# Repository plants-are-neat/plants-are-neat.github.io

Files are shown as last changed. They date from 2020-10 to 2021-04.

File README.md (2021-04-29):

# Team 27 README
## Introduction
Hello, welcome to plants are neat! Throughout this project, we developed a mesh sensor network system capable of self-healing and communicating data from node to node. The data is routed through the network of nodes to find an access point to push data to the online database. The online database is a relational database organized through the thingspeak API to track independent channel ids, field ids, field values, and time data. We can pull the most recent data point to create google gauges with the most recent data point with this data. Notifications are handled through server-side react scripts and test the database to ensure data coming in is within given thresholds and that each node that should be in the network is successfully communicating data. Broken nodes are identified by a lack of data received by a gateway node over a 30 min period. This enables users to fix problems in the field without getting constant notifications. Broken nodes check for fixes every 30 minutes.

## Getting Started
1. Populate the PCB using the schematic and BOM.
2. Solder wires to the battery breakout and have them ready to connect to the battery, but do not connect the battery yet.
3. Install the vent plugs into the enclosure.
4. Drill holes into the enclosure for the external antenna, soil temperature sensor, soil moisture sensor, and the solar panel DC jack.
5. Thread the soil moisture sensor and the soil temperature sensor through the holes and solder them into place using the schematic.
6. Screw the PCB into the enclosure.
7. Using weatherproof epoxy, fix the antenna, soil sensors, and solar panel DC jack into place and let cure overnight.
8. Upload any relevant code to the Featherboard using the Software_README.md file.
9. Insert the Featherboard into the PCB.
10. Connect the solar panel DC jack to the PCB DC jack.
11. Connect the battery to the battery breakout on the PCB.
12. Close the enclosure and place it in the proper location.
13. Open .ino using Arduino IDE
14. Connect Feather M0 to computer using usb-microusb
15. Hit ‘Upload’ on upper left-hand corner
16. Wait for upload to finish
17. Install NODEJS https://nodejs.org/en/download/
18. Make sure MotherNode is connected to computer, CANNOT be used by another program, connection will be blocked
19. Open command prompt
20. Go to directory where file is
21. Run command "Node SerialTest.js”
## Current State
The current state of the project features a mother node requesting data from all the outer nodes, and the outer nodes collect data (soil moisture, soil temperature, ambient temperature, humidity, and sunlight intensity) and sending the data to the network. As stated in the introduction, the project also includes a thingspeak API, graphical representation of the collected data, and broken node email notifications.
## Failure Modes and Gotchas
| Gotcha  | Reason | Solution |
| --- | --- | --- |
| Boost converter auto bypass nonfunctional | The MOSFETs’ gate voltages are not defined at startup | Use pullup resistors on the MOSFET gates to Vcc |
| COM port disconnects | COM ports can disconnect after successfully uploading code to the Featherboards | Use the Arduino IDE to pick the new COM port corresponding to the correct Featherboard |
| Delayed email notifications | gmail firewalls | alternative notification system |
| Self healing requires correct installation | If each node is not installed within range of at least two other nodes, the network may not be able to self heal | Make sure that each sensor node is installed within range of at least two other sensor nodes |
| NODEjs crashes upon selecting a port | Serial ports can’t be read using different programs simultaneously | Close all other applications reading or writing to the port, most likely culprit is the Arduino IDE | 
## Possible Future Improvements
- Expanding the node network beyond our test 4, integrating automatic node IDs and being able to toggle between all of these data displays
- Change visualisation page to display multiple nodes at once. 
- Expanded sensor readings
- Use wifi-enabled board so it can run continuously
- Fix boost converter auto-bypass issue
- Use a Raspberry Pi as a continuously running server that can read serial data via USB input

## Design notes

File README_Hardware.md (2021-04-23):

# Team 27 Hardware README
## Introduction
The smart agriculture sensor network is comprised of sensor nodes and one gateway node. The gateway node is simply a LoRa-equipped microcontroller, namely the Adafruit FeatherM0 LoRa microcontroller board. The sensor nodes also include a LoRa microcontroller, but it is mounted on a PCB that includes all of the power electronics and all of the sensors for the sensor node. All schematics and layouts can be found in the directory "Schematics and Layouts".

## System Design
The gateway node electronics consist solely of the Adafruit FeatherM0 LoRa microcontroller board, which is connected to a laptop or desktop computer via a micro-USB cable. The sensor nodes, however, are more complex. 

The sensor nodes are capable of measuring ambient temperature, humidity, ambient light, soil moisture, and soil temperature. There are breakouts on the PCB so the user can add more sensors that may be more specific to the farming task. The sensor nodes also features solar energy harvesting with a solar panel and a solar battery charging and power path management system. Thus, the requirements met by the hardware of the project are: 
1. The sensor nodes must be powered for one year continuously.
2. For 100 sensor readings in identical conditions, the sensor data should not deviate by more than +- 5% of the mean.

Requirement number 2 is met by the onboard sensors, which use the I2C protocol if they are digital sensors and act as voltage dividers if they are analog sensors. The LoRa Featherboard is natively I2C compatible, so it can poll the digital sensors without any additional components which are not recommended by the sensor manufacturer. The Featherboard also has an on-board analog-to-digital converter (ADC), so there is no need for a separate external chip to allow the processor to communicate with the digital sensors. Requirement number 1 is met by the power path management and solar battery charging system. These two subsystems are discussed in detail in the PCB Design section.

The sensor node consists of a populated PCB, an Adafruit FeatherM0 LoRa microcontroller board, an external antenna, a battery pack, an enclosure and other mechanical components, and a solar panel. A bill of materials for one sensor node is presented below. Recall that the gateway node consists solely of one Adafruit Featherboard, and is not listed here. Also included in this BOM is the soil moisture sensor, which is not available at Digikey. All other components for the PCB were purchased at Digikey and are available in the PCB Design section.

### Sensor Node Equipment BOM
| Item Number  | Item | Vendor | Link | Quantity |
| --- | --- | --- | --- | --- |
| 1 | FeatherM0 LoRa microcontroller | Adafruit | [Link](https://www.adafruit.com/product/3178) | 1 |
| 2 | Large 6.5V 3W solar panel | Adafruit | [Link](https://www.adafruit.com/product/500) | 1 |
| 3 | ICR18650-30Q Li-Ion Battery Cells | 18650 Battery Store | [Link](https://www.18650batterystore.com/products/samsung-30q) | 4 |
| 4 | Custom PCB | JLCPCB | N/A | 1 |
| 5 | VH400-2M soil moisture sensor | Vegetronix | [Link](https://www.vegetronix.com/Products/VH400/#order) | 1 |
| 6 | Nema 4X enclosure | Solutions Direct | [Link](https://www.solutionsdirectonline.com/hammond-4x7x7-polycarbonate-electrical-enclosure-with-clear-cover-1554wa2gycl) | 1 |
| 7 | Pressure equalization vents | Solutions Direct | [Link](https://www.solutionsdirectonline.com/enclosure-vent-plug-m12-x-15-2-pack--284060-00-p6062.aspx) | 1 |
| 8 | LoRa 900MHz antenna | Adafruit | [Link](https://www.adafruit.com/product/3340) | 1 |

The Featherboard is inserted into the assembled PCB as directed by the silkscreen. The battery is connected to the P1 breakout on the PCB with the battery positive going to the square hole. The solar panel male DC jack is inserted into the female DC jack on the PCB. When populated and programmed, the hardware should be powered, be able to run, collect data, and send and receive packets via LoRa.

The system requires at least 4.5V at the DC jack input to function without battery power, so for testing purposes a 5V wall adapter will work. The maximum input voltage at the DC jack is 10V. Since the solar panel can only output an open circuit voltage maximum of 6.5V, this shouldn't be an issue, but the PCB has a zener diode to clamp the input voltage in case of emergencies. The PCB also has a boost converter for low light conditions, which is discussed in the PCB design section.

The Featherboard uses an external 900MHz antenna for long distance communication with other sensor nodes. It is installed on the outside of the enclosure so that line-of-sight is not obstructed.

Pictures of the assembled system are shown below:

### System Images
Hardware angle 2
Hardware angle 4

## PCB Design
The PCB consists of three main sections:
1. Input power electronics and solar charging and power path management.
2. Featherboard harnessing and breakouts.
3. Digital and analog sensors.

An image of the rendered PCB layout with the above sections marked is shown below:
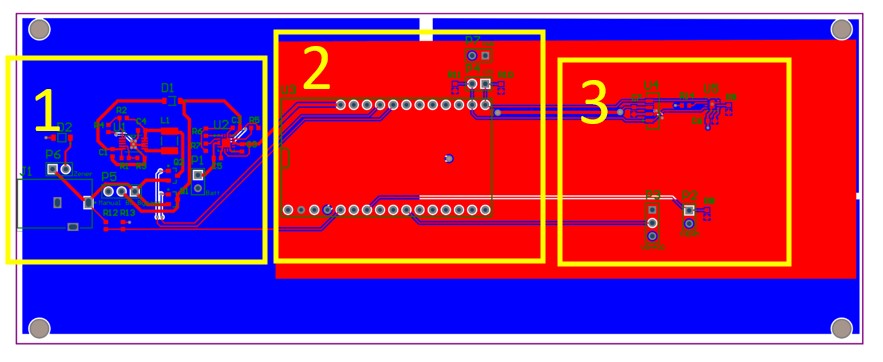
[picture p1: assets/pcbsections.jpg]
PCB Sections


### PCB Section 1: Power Electronics
The largest and most important subsection of section 1 of the PCB is the solar charging and the power path management, which is accomplished using the BQ24074 (item #2 in the PCB BOM). The BQ24074 is a standalone 1.5A linear battery charger with power path management. The design of this IC on the PCB was implemented using the application notes section of the datasheet provided by Texas Instruments and accessed from Digikey. Using the application notes, the Enable pins E1 and E2 were tied high and low respectively, causing the IC to be USB compatible with a maximum input current of 500mA. A temperature sensor for the battery pack was not implemented, so in it's place a 10k resistor was selected as R7 to permanently cause the IC to be active. R5 and R6 were selected to both be 2.2k, which makes the input current limit and the fast charging current to be the same value, and is set to 400mA. The input and output capacitors as well as the bypass capacitors were selected based on the application notes' recommended values. The PCB layout of this subsection was informed by the layout recommendations in the application notes, with special considerations for hand-soldering of SMD parts and the placement of the PCB and battery within the enclosure.

The other main subsection of section 1 is the low-light boost converter, which boosts the solar voltage to a level that will operate the Featherboard and sensors in low-light conditions so that the battery does not have to discharge as much. This is accomplished using the MCP16414 (item #1 in the PCB BOM). The MCP16414 is a low quiescent current low input voltage minimum programmable boost converter. The design of this IC on the PCB was implemented using the application notes section of the datasheet provided by Microchip and accessed from Digikey. R1 and R3 were selected to be 1.5Meg and 360k respectively to give an output voltage of 5V, as specified in the application notes. The switching inductor as well as the input and output capacitor values were also taken from the application notes' recommended values for 5V output operation. The PCB layout of this subsection was informed by the layout recommendations in the application notes, with special considerations for hand-soldering of SMD parts. 

The MCP16414 maximum input voltage is 5.25V, and since the solar panel output can reach 6.5V, an automatic bypass system was implemented using P-channel MOSFETs (Q1 and Q2 in the PCB BOM), which are controlled by the Featherboard. This subsection is currently experiencing a bug where the MOSFET gates are floating on startup, and thus the boost converter is not properly bypassed, which causes the input voltage to short to ground through the boost converter. A better solution for future beta versions of the project would be to implement the automatic bypass with analog electronics, so that the propagation delay of the control signals to the P-channel MOSFETs is much less. Additionally, including pull-up resistors and diodes (to the solar panel input and the battery positive) on the MOSFET gates will establish a gate voltage immediately. This issue was known prior to the end of the semester, but was not implemented in the alpha version of the project due to issues with working remotely and time constraints. The entire system needed to be passed around for other tasks, and in order to have a completed project by the end of the semester this issue was not addressed, although there are proposed solutions presented here.

### PCB Section 2: Harnessing and Breakouts
This section is where the Featherboard is inserted into the PCB. The section also includes 3.3V and ground breakouts to power other sensors, as well as I2C clock and data line breakouts for exteral digital I2C compatible sensors.

### PCB Section 3: Sensors
This section consists of the digital and analog sensors that are polled by the Featherboard. The sensors used are:
* SHT31-D (item #4) to measure ambient temperature and humidity.
* VEML7700 (item #3) to measure ambient light.
* 10k NTC thermistor with K constant 3435K (item #19) to measure soil temperature.
* VH400-2M (item #5 in the system design BOM) to measure soil moisture.

The digital sensors were implemented on the PCB and their layout was done using the application notes in their datasheets provided by Sensirion (SHT31-D) and Vishay (VEML7700) and accessed from Digikey. The VH400 was connected according to the tutorials provided by Vegetronix, and the thermistor was connected in a voltage divider configuration according to a tutorial made by Adafruit. Both the digital and analog sensors are powered from the Featherboard's on-board 3.3V regulator. The analog sensors are grounded via a ground plane that spans the entire PCB, including the power electronics. The digital sensors were grounded separately from the analog sensors, and were grounded directly to the Featherboard ground in order to eliminate any capacitive coupling from the power electronics via the large ground plane.

### PCB BOM
| Item Number | Designator  | Value | Footprint | Quantity | Digikey Part # |
| --- | --- | --- | --- | --- | --- |
| 1 | U1 | MCP16414-I/UN | MSOP-10 | 1 | 150-MCP16414-I/UN-ND |
| 2 | U2 | BQ24074RGTR | 16-QFN | 1 | 296-38873-1-ND |
| 3 | U4 | VEML7700-TR | 4-SMD, J-LEAD | 1 | VEML7700CT-ND |
| 4 | U5 | SHT31-D | 8-VFDFN | 1 | 1649-1011-2-ND |
| 5 | Q1,Q2 | STR2P3LLH6 | SOT-23 | 2 | 497-15520-1-ND |
| 6 | J1 | PJ-102B | DC Jack | 1 | CP-102B-ND |
| 7 | D1 | RB161MM-20TR | SOD-123F | 1 | RB161MM-20CT-ND |
| 8 | D2 | MMSZ5233BT1G | SOD-523 | 1 | MM5Z5V1ST1GOSCT-ND |
| 9 | L1 | 4.7uH | 1812 (4532) | 1 | 490-2517-1-ND |
| 10 | R2,R4,R10,R11 | 4.7kR | 0603 (1608) | 4 | CRCW06034K70JNEBCCT-ND |
| 11 | R5,R6 | 2.2kR |  0603 (1608) | 2 | 541-4058-1-ND |
| 12 | R7,R8,R9,R12,R13 | 10kR | 0603 (1608) | 5 | 13-RE0603FRE0710KLCT-ND |
| 13 | R1 | 1.5MR | 0603 (1608) | 1 | 311-1.5MGRCT-ND |
| 14 | R3 | 360kR | 0603 (1608) | 1 | 311-360KGRCT-ND |
| 15 | C1,C4 | 10uF | 0603 (1608) | 2 | 478-10766-1-ND |
| 16 | C2 | 1uF | 0603 (1608) | 1 | 587-1248-1-ND |
| 17 | C3,C5 | 4.7uF | 0603 (1608) | 2 | 1276-1902-1-ND |
| 18 | C6,C7 | 100nF | 0603 (1608) | 2 | 1276-1931-1-ND |
| 19 | P2 | 10k NTC 3435K | 2-LEAD | 1 | BC2647-ND |

## Installation and Instructions for Engineers
Instructions on how to assemble and install a sensor node are listed below:
1. Populate the PCB using the schematic and BOM.
2. Solder wires to the battery breakout and have them ready to connect to the battery, but do not connect the battery yet.
3. Install the vent plugs into the enclosure.
4. Drill holes into the enclosure for the external antenna, soil temperature sensor, soil moisture sensor, and the solar panel DC jack.
5. Thread the soil moisture sensor and the soil temperature sensor through the holes and solder them into place using the schematic. 
6. Screw the PCB into the enclosure.
7. Using weatherproof epoxy, fix the antenna, soil sensors, and solar panel DC jack into place and let cure overnight.
8. Upload any relevant code to the Featherboard using the Software_README.md file.
9. Insert the Featherboard into the PCB. 
10. Connect the solar panel DC jack to the PCB DC jack. 
11. Connect the battery to the battery breakout on the PCB. 
12. Close the enclosure and place in the proper location.

Note: for optimal self-healing performance, place each sensor node within range of at least two other sensor nodes.

To install the gateway node, plug it into a laptop or desktop computer using a micro-USB cable, connect the external antenna, and follow the instructions in the Software_README.md file.

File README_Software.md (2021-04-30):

# Team 27 Software README
## Introduction
The smart agriculture sensor network is comprised of sensor nodes and one gateway node. The project requires a node.js server to communicate with the ThingSpeak IoT channels. While the project was developed in a Windows operating system environment, most of the files can be run in different operating system except for the batch files. Correct installation of node.js is also required to allow the project to work properly. The outer microprocessors (nodes) are flashed with a program that allows them to collect sensor data when not sleeping to conserve energy. The node.js server receives information from the mother microprocessor via serial communication to be sent to a remote website.

## Files
CODE ON ARDUINO IDE:
Adafruit Library installed
 1. Sensor_Node_X.ino:
 
This program serves as the outer node code for nodes with sensors out in the field. It starts off by initializing the radio unit on the onboard feather and setting pins as outputs and inputs for the sensors on board. Each sensor runs through its own initialization. The radio unit has fail safes that does not let the code run if it does not initialize properly. The code then executes. It takes the reading from its sensors, puts the readings in a string, and then sends the string through the radio. Collected information will depend on the user's decisions on what to implement. In this project, the node will collect humidity, soil and ambient temperature, soil moisture, and sunlight intensity. The radio library allows for rerouting in the case of a broken node and self healing as well. The message gets routed all the way to the mother node. After sending the message the board activates its sleep protocol and 'sleeps' turning off most systems to conserve power. It wakes up after a set amount of time and repeats. The sleep function allows the use of the microprocessors specific power modes thus the need of other libraries might be necessary.

    -C++/C
    -Dependencies
      -RadioHead.h             // For the onboard radio
      -SPI.H                   // For on board communication with the sensors 
      -Adafruit_VEML7700.h     // Ambient light sensor
      -Adafruit_SHT31.h        // Humidity sensor
      -Adafruit_SleepyDog.h    // Sleep protocol for the board

 2. client_node.ino

This program serves as the mother node of the network. Starts off by initializing the radio. Periodically polls the other nodes with sensors and polls them to give it information. Upon receiving a message, it prints it out to the COM port for the computer to read. Repolls and repeats.
    -C++/C
    -Dependencies
      -RadioHead.h             // For the onboard radio
      -SPI.H                   // For on board communication with the sensors 
--TO RUN--
1. Open .ino using Arduino IDE
2. Connect Feather M0 to computer using usb-microusb
3. Hit Upload on upper left-hand corner
4. Wait for upload to finish

CODE ON DEKSTOP
NODEJS installed
  1. SerialTest.js

SerialJS does a few things for the mesh. Firstly, it uses an external library to prompt the user for which active port to use. IMPORTANT: The code cannot execute if another program, such as the Arduino IDE is using the COM port, meaning if the Serial Monitor is open and listening in on the COM port it will terminate with an error. Terminating with an error should be avoided. It then reads from the port and saves it within the code to use the second library to send it over to the ThingSpeak IoT channel. The message from the arduino is then chopped up between the partitions, in this case commas, and sent to their specific fields. It then repeats this and sends whenever there is a new message. Messages that are way below and above certain thresholds are deleted and ignored.
     -NODEJS
     -Dependencies
        -ThingSpeakClient    // For updating the ThingSpeak channel
        -serialport          // For reading the serial COM port
        -prompt-sync         // Used for prompting the user
--TO RUN--
1. Install NODEJS https://nodejs.org/en/download/
2. Make sure MotherNode is connected to computer, CANNOT be used by another program, connection will be blocked
3. Open command prompt
4. Go to directory where file is
5. Run command "Node [FILENAME]" where [FILENAME] is the name of the file with the extension

CODE ON WINDOWS
1. PANinstall.bat

_TITLE Dependencies Installation
ECHO Installing dependencies, please wait!                              //Echo just prints out a statement
npm install thingspeakclient                                            //installs the thingspeak client library
npm install serialport                                                  //installs the serial reader
npm install prompt-sync                                                 //installs the prompt to ask the user
ECHO All dependencies downloaded, thank you for your patience!          //Prints out the final message
PAUSE                                                                   //Waits for a user input to move_

This batch file is made for the simplicity of the user. Since the developing team consisted of only window users, the installation and batch file was developed only for a windows environment. As a result, future improvement include the implementation of the batch file to work in different operating systems like iOS, Linux, Unix, etc. This batch file installs all NODEjs libraries. It executes and downloads the libraries and waits for the user to close the command prompt.

2. runMESH.bat

_node SerialTest.js                                                     //THis is how a js script is ran
PAUSE                                                                   //Leaves the prompt open, do not stop the prompt_

This batch file is made for the simplicity of the user. On the team, there are only windows users so we could not develop this for other operating systems. This batch file executes the SerialTest.js. It runs and the promp should be left open for the code to keep executing.

  -Dependencies
    -SerialTest.js
--TO RUN--
1. Open any command prompt
2. Go to where the .bat files are (they should be grouped together, with the NODEJS code)
3. Double click PANinstall.bat first, runMESH may not run if done out-of-order
4. Double click runMESH.bat

## Libraries
The main two libraries used in the nodes are RH_RF95 and RHMesh. Both libraries are part of a larger library named RadioHead that allows the use of long range (LoRa) radio communication installed in the Arduino. 

RH_RF95 allows the use of two radio wave (868 and 915) lengths. To comply with US regulations, we chose 915 as the default wave length of the network. This can be changed to 868 at the top of each file depending on the user’s country’s regulations. The library is the foundation of the other libraries since the library grants the ability to send and receive packages of information via an object-oriented format. The library consists of drivers and managers to modulate the communication requirements of different microprocessors. While this library allows the communication between nodes, further libraries are needed to achieve the mesh network behavior of route discovery, creation and maintenance of a routing table, and self-healing capabilities. As a result, the next library is needed. Further documentation can be found here: https://github.com/kenbiba/RH-RF95 

RHMesh allows the use of a mesh network behavior into the microprocessors instead of naive communication protocols. It includes automatic route discovery when initializing the drivers and managers as well as multi-hop routing capabilities thus allowing self-healing if a node is corrupted/broken. This is achieved via the use of routing tables first initialized when initializing the manager and sending the first message to the desired address/location. Even if the message fails to send to the desired node/location, the intermediate nodes are registered into the routing table for an up to date information on the most efficient route to each node. A future improvement to the library can be to decrease the situations that create races. The library is an extension of a different library called RHRouter which is the foundation of the RHMesh library. Further documentation can be found here: https://www.airspayce.com/mikem/arduino/RadioHead/classRHMesh.html 

The two main libraries used in the desktop are the serialport and the ThingSpeakClient libraries. Both are independent of each other and are stand-alones.

ThingSpeakClient enables communication with ThingSpeak's servers. There are built in functions for validating requests to read or write and alraedy has all the information necessary to initiate communication between the servers. The library also has built-in functions for enabling the coder to write to specific graphs within the channel. There are a few limitations with the library. Depending on what specific service the user has with ThingSpeak, there is a possibility of messages getting backlogged. For the purposes of this however, unless nodes exceed a normal amount, should not happen.

Serialport enables communication with usb enabled devices. The library uses a parser as well to be able to read what is inputed into it. It takes whatever it receives and is saved on memory. Using this instead of other means that it is incredibly reliable due to built-in error finding on computers when compared to wireless means. If the port is being used by another program it will exit with a fatal error.

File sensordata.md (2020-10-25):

---
title: Sensor Data
layout: default
---
### Sensor Data
The following is an example how data will be presented: <br>
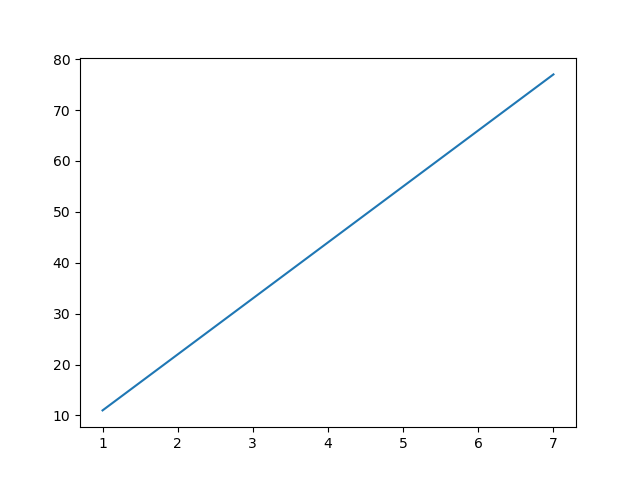
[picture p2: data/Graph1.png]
hi


### Current nodes offline include:
None at the moment

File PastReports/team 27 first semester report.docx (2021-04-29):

ENG EC 463 – Team 27

Smart Agriculture Sensor Network

First Semester Report

Benjamin Livney, Maxine Loebs, Sergio Pareja, Emanuel Perez and Noah Spahn

Executive Summary (M.L.)—Farming is paramount to society. Throughout history, as global populations have increased, farming methods have had to improve to keep up with growing demand. Today, the situation is no different – with more and more mouths to feed, farmers are looking to modernize their practice and adopt technologies that can help them boost crop yields, reduce waste, save money, and stay afloat among industrial-scale agricultural corporations. To address this need, we will be developing a fully-functional agricultural sensor network, which reports data about specific locations on the farm back to the user in the comfort of their farmhouse. We have come up with a detailed plan to realize our design. The backbone of our final product is our sensor nodes. These will contain our selected sensors, a microcontroller equipped with a radio transceiver, and the required hardware to supply power to all of the electronics inside. All of the components will be put into a weatherproof enclosure. All of these nodes will be connected together in a scalable mesh network. The data from all of the nodes will be pooled into a single gateway node, which will then send compiled data to our web console. Our web console will present this live data in a neat, readable format. There are other agricultural sensor networks on the market, but our product will include a number of innovative features that make it stand out, such as energy harvesting, and the use of a wide variety of sensors to paint a full picture of many conditions out in the field.

—————————— ——————————

# 1 Introduction (M.L.)

In recent years, farmers have been embracing technology to supplement and/or replace more traditional farming methods in order to increase crop yields, lower the cost of production, reduce waste, and – in the case of smaller, local farmers – remain profitable and competitive in a market that is dominated by large-scale agricultural corporations.

As such, we are being tasked with creating an agricultural sensor network to help accomplish all of these things. The network will allow the farmer to be aware of the conditions at any location on his farm at which an individual sensor node is placed, all without having to actually step foot out into the field, as the data will be available to view on a web console. This saves time and money. The farmer doesn’t have to drive around the farm himself to check on things, or pay people to do the same. Some farms – even those owned by small farmers – are massive in size, so checking up on areas of the farm could become quite time-consuming, even when done only once a day. Having insight into the current conditions around the farm additionally allows the farmer to save money by being able to better distribute resources. For example, the device will have a soil moisture sensor. By monitoring soil moisture, the farmer can in turn adjust how much he is watering different areas of his fields, preventing overwatering and in hand saving money. With knowledge of field conditions, the farmer can make adjustments to ensure ideal conditions for achieving the most successful crop, and thus achieve higher profits.

We have come up with a detailed plan for the implementation of our design. Our network will consist of sensor “nodes” which will collect and relay data back to a single gateway node. These sensor nodes will, as the name would suggest, contain all of our sensors. We are planning to gather data pertaining to air temperature, humidity, barometric pressure, ambient light, soil temperature, and soil moisture. The data readings give the farmer a full picture of their crop’s current environment. Since the information needs to get back to the farmer, each node is also equipped with a transceiver. We will set up a mesh network protocol that will allow information to bounce from node to node until it gets back to the gateway. If one node in the chain is not able to relay data, the mesh networking protocol will allow for a new route to be discovered. Of course, both the sensors and the microcontroller need to be powered. We will use both a battery pack and a solar panel to provide power. The solar panel can also recharge the batteries. The electronics will be housed in a weatherproof container, which will protect our electronics from rainfall, windblown dust and dirt, and the formation of ice in colder months. The gateway node, which will be located in the farmhouse, is where all the data will be pooled from all of the sensor nodes out in the field. In addition to a transceiver, this node will also have a co-processor that will allow data transmission over WiFi to our web console. Our web console, upon receiving live data, will display the data in graphs that will allow the user to see changes in conditions over time. This is a powerful tool, since seeing trends of data, rather than just individual points in time, further allows the farmer to make predictions and adjustments in his plan to achieve the best crop.

There are other products on the market that seek to accomplish the same goal as our prototype: to provide farmers data about their farms via a network of sensors. We are including a number of features that make our product different. We will be using a number of different sensors, mentioned previously, that will provide the farmer with a multitude of data pertaining to both atmospheric and soil conditions. Many companies only produce nodes that report back one type of data reading, or require users to purchase several different models to get a wider variety of data. Additionally, with the use of energy harvesting, we are greatly able to extend the battery life of our nodes. In fact, our nodes will be able to last at least one year between charges. Many companies rely solely on battery power for their nodes, so they need to be recharged much more frequently, creating more work for the farmer.

# 2 Concept Development (M.L.)

To develop our concept for design, we identified key functions to be fulfilled by our prototype, and then came up with solutions to address each function.

Our sensors must operate as a network, and therefore communicate with each other, and not just with the gateway node. As such, we decided to use a mesh networking protocol. This has a number of benefits. Broken or unresponsive nodes can be identified, and since signals bounce from node to node in a mesh back to the gateway, a new route can be discovered to avoid the broken node until it is repaired, so that all other data from working nodes can still make its way back to the user. Since we are not sending data directly back to the gateway, but rather bouncing the signal back via other nodes, we also do not need a massive signal transmission range.

With the basis of our network established, we had to choose how our data would be transmitted. Eventually, we decided to use LoRa (Long Range) RF transmission-equipped microcontrollers. The microcontrollers, with the proper antennas, are able to transmit data across several kilometers while using very little power. We have set our node-to-node transmission range goal to be between 750 m and 5 km. We had considered some other methods of data transmission, such as equipping our nodes with SIM cards to connect to a cellular network, but we soon decided that this would become expensive, complicated, and use too much power.

Our nodes must be able to last at least one year between charges. This means that we had to carefully consider what devices we would use and how much power they would draw, and what we would use to provide power. At first, we considered just equipping the nodes with a massive battery pack, but we decided that this would become too bulky if they had to last an entire year, and that we were capable of something more innovative. It was suggested that we look into energy harvesting. We looked into both solar and thermoelectric energy harvesting. Ultimately, solar energy harvesting with a solar panel was the clear winner, as we were able to propose an implementation that would provide a much greater amount of power. So, our final powering solution consists of a combination of battery pack and a solar panel. The solar panel can recharge the batteries and supply power directly to the electronics inside the node as well.

The information that we are sending back to the user must be useful for farming. We carefully considered the sensors that we would be using in our prototype – air temperature, humidity, barometric pressure, ambient light, soil temperature, and soil moisture – making sure that the information they provided could be used to gain insight into how to achieve the best crop. We also considered including a sensor to measure soil pH, but these kinds of sensors, however, require relatively involved and individual calibration.

Lastly, we needed to make sure that our sensor nodes are weather-resistant. Water and dust should not be able to get inside of our node and damage our electronics. We researched different weathe-rproofing standards, and determined to aim for at least IP43 compliance, which would protect our electronics from spraying water.

We have tabulated a formal list of engineering requirements, that can be quantifiably measured, in Appendix 1.

# 3 System Description (B.L.)

As a solution, a mesh sensor network utilizing the LoRa communication protocol will be developed. The network will consist of many sensor nodes outfitted with relevant sensors, energy harvesting equipment and electronics, and a LoRa RF-equipped microcontroller. The network will also have a gateway node to collect data from the sensor nodes and push it to a web console to be viewed by the user.

Each sensor node will be outfitted with a solar energy harvesting system incorporating a small photovoltaic (PV) module and power electronics to maintain power for at least one year. Nodes will be equipped with a 3W 6.5V PV module capable of providing a maximum of 460mA in high light conditions. In order to not drive the module too hard, a maximum battery charging current of 400mA is set by the battery charge IC, the BQ24074. For low light conditions, a low-power boost converter, the MCP16414, will boost voltages above 1V up to 5V to operate the BQ24074 correctly and to power the microcontroller and sensors. The boost converter will have both a manual and an automatic bypass to ensure use only in low-light conditions to maximize efficiency, and to ensure the maximum input voltage to the boost converter of 5.25V is not exceeded. The battery pack will be between 12000mAh and 18000mAh, which will ensure sufficient power for three weeks with no sun, assuming an average current draw of 25mA from the microcontroller and sensors. This large backup battery will help meet the power budget requirements in conjunction with the solar energy harvesting system.

The sensor nodes will feature both digital and analog sensors capturing data to represent a variety of factors that affect growing conditions. The sensors will consist of: the BME280 to measure temperature, humidity, and barometric pressure, the VEML7700 to measure ambient light intensity, the VGH400 to measure soil moisture, and an NTC thermistor to measure soil temperature. Monitoring these quantities are basic necessities in order to create optimal growing conditions. For more specific applications, additional digital and analog sensors can easily be added to reflect the needs of a specific location. Additional sensors could include UV index sensors for UV-specific crops and motion sensors for wildlife tracking.

The LoRa communication protocol allows for wireless communication and mesh networking between LoRa-enabled devices using a tunable 900MHz carrier signal without the need for cell service, Wi-Fi, or Bluetooth capabilities. This protocol will be used to create the mesh sensor network by establishing a gateway node that sends poll requests and waits for responses. As shown in Figure 1, each sensor node will listen for incoming LoRa messages, either from the gateway node or from other sensor nodes. If the incoming message is not a poll request, meaning the message contains sensor readings, the sensor node will use the established mesh protocol using LoRa to repeat that message, sending it closer to the gateway node for analysis. If the incoming message is a poll request, the sensor node checks if it is polling itself, in which case it takes sensor readings and sends them to the mesh network. Otherwise, it repeats the poll request so that other nodes out of range of the gateway can receive it.

The gateway node will, at regular intervals, send poll requests to the mesh network for data from specific sensor nodes. As described above, the sensor nodes will echo the poll request until it reaches its destination, at which point the data will be sent and echoed back. If the gateway node receives a response before a timeout, it will push it to the web console for processing using an ESP8266 Wi-Fi enabled module. If no response is received before the timeout, the gateway node will push a notification to check the status of the requested node. Since the network should be installed such that every node is in range of multiple other nodes, there will be many paths from the gateway to any requested node. Thus, if a timeout occurs, the gateway will know that the requested node is at fault and not some other sensor node.

Once sensor readings from sensor nodes have reached the gateway node, the data will be processed by ThingSpeak IoT, a free IoT data visualization tool running off of MATLAB. This tool can create live-updating graphs using MATLAB plotting functions that run as embedded HTML divs. The gateway node, running inside the farmhouse, will have access to Wi-Fi, and thus will send sensor readings to ThingSpeak IoT, which will store, plot, and update the data live in an HTML webpage for the user to see. Data will not be pushed and stored in a JSON object, which can be read by ThingSpeak IoT.

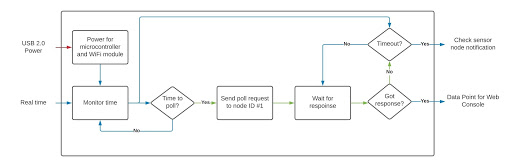
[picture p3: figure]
Word template Figure 1

Fig. 2. A functional analysis of the gateway node describing poll requests, responses, and interaction with the web console.

# 4 First Semester Progress

## 4.1 Current Network Protocol (E.P.)

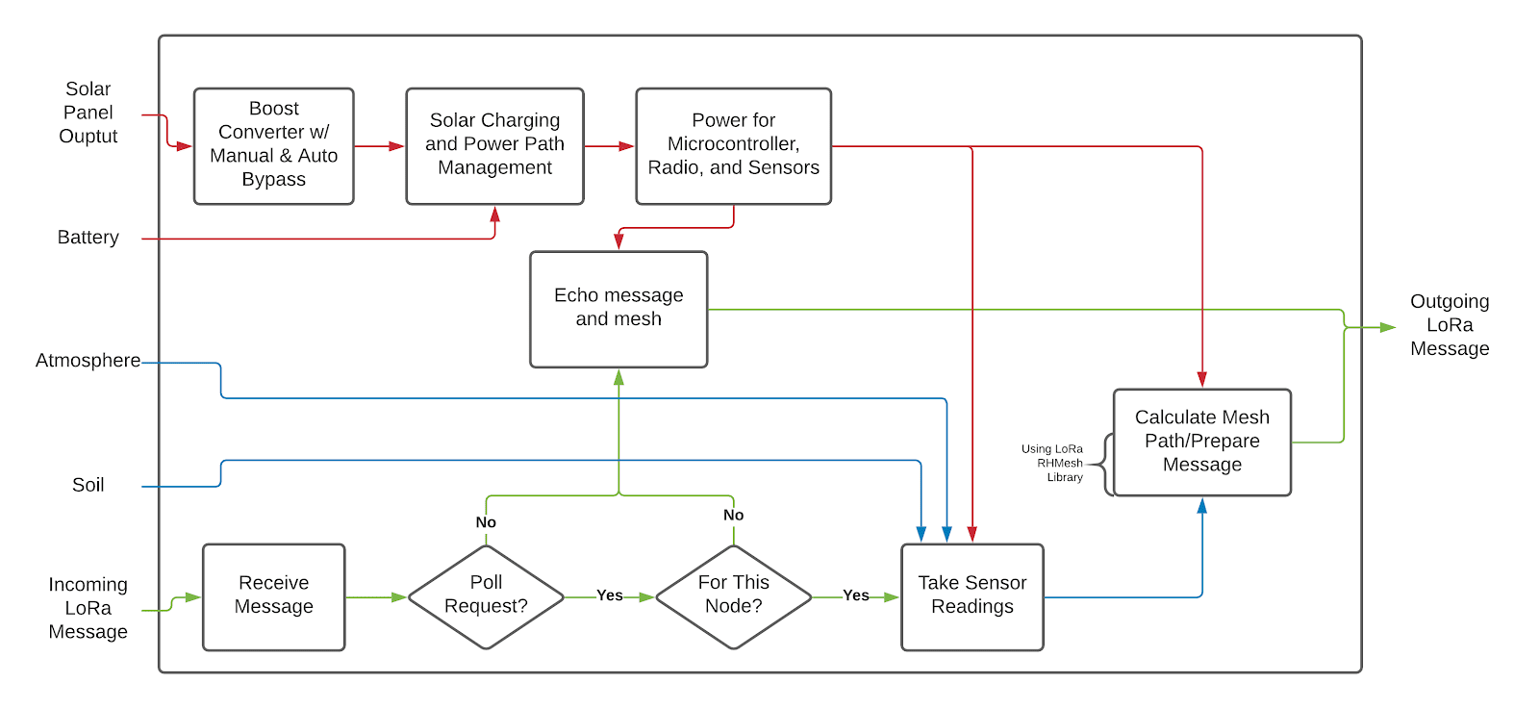
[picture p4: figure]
Word template Figure 1

Fig. 1. A functional analysis of a sensor node describing power flow, sensor operation, and LoRa mesh networking.

During the first prototype testing, we used a different network protocol than the mesh network to test the communication between our nodes. Similar to the mesh network, the network consists of a mother node (gateway node) and outer nodes (sensor nodes). The mother node sends poll requests for a specific node to the network. With the use of the LoRa microcontroller, the poll is sent via radio waves to nearby listening nodes. The receiving nodes will send an acknowledgement depending on whether or not it’s the node the mother node is looking for. If it is, the node will send the current sensor data back. If it isn't, it will send a simple acknowledgement and send the poll to other nearby nodes.

## 4.2 Power Management (E.P.)

To meet the client’s battery life expectancy of one year, the device has the ability to sleep/wake for an X amount of time. During the device’s sleep cycle, all electronics and internal functions are stopped. Once X amount of time passes, the device is woken up via a watchdog timer. If the desired amount of sleep is greater than the watchdog timer’s limit, then the device wakes up momentarily to sleep again till it reaches the desired amount. The current sleeping protocol can save up 40% of energy consumption than just the device being idle.

## 4.3 Power Electronics (B.L.)

For the first prototype test, we demonstrated the power path management abilities of the proposed system. We were able to charge a Li-Ion battery through the power path management IC, deliver power to a load from an external power supply through the IC, and power the same load from the battery through the same IC. From previous testing, it was shown that the battery could be charged from the solar panel with up to 160mA on a partly-cloudy New England winter day, and with up to 50mA while obstructing the solar panel, simulating shadows. This IC was then integrated into a PCB, also including low-light power adjustment with a boost converter, as well as the microcontroller and sensors. Schematics for the power electronics and sensor electronics are shown in Appendix 3.

## 4.4 Power Electronics (B.L.)

Using the I2C communication protocol, we were able to demonstrate data collection from multiple digital and analog sensors at once, and the formatting of data points into a string to be sent by the LoRa module. This was accomplished with the use of sensor breakout modules, inexpensive PCB sensor products meant for modular testing and projects that do not feature best practice layout techniques: ground between the data lines to reduce crosstalk and star grounding with separate ground planes for analog and digital sensors. The PCB we designed does feature those best practices, which will serve to improve reliability and precision in data collection. Schematics for all the electronics, as well as a preliminary PCB layout, are shown in appendix 3.

## 4.5 Enclosure (M.L.)

Our chosen enclosure, the Hammond 1554WA2GYCL, goes beyond the weather protection of our initially-set IP43 requirement, which provides protection against spraying water. It is a 7.1” x 7.1” x 3.54” polycarbonate box with a removable clear lid. It has a NEMA 4X rating, meaning that it is watertight, protects against dirt, dust, and the formation of ice, and is corrosion resistant. The size of this enclosure leaves us with ample room for our PCB, with all attached components, and our battery pack. The clear lid allows us to take readings of ambient light. To get accurate sensor readings of humidity and barometric pressure, two Stego 284 vent plugs were installed on opposite sides of the enclosure, 2” from the side and 0.75” from the top. These allow air into the enclosure and equalize the pressure inside and outside of the enclosure, while maintaining the NEMA 4X rating. Pressure equalization has the added benefit of protecting from condensation building up inside the enclosure with changes in temperature. Next steps will include making more through-holes for sensors and possibly the antenna, and then making sure they are sealed properly. A picture of the enclosure is shown in Appendix 3.

## 4.6 Current Web Application (N.S.)

In order to demonstrate the WebApp visualization portion of the client’s needs, we utilize a Matlab analysis script, and the ThingSpeak IoT tool to upload data and analyze the uploaded data into a visualization. We were able to upload data through a microcontroller WiFi shield simulator as well as in a local Matlab script. Testing determined that there is a minimum of 10 seconds between uploads. The frequency of data collection will not be near this fast. The visualization is done through ThingSpeak with a server-based Matlab script. During our test we demonstrated that the visualization, embedded into the console webpage, live updates to display exact data and timestamp the data pushed from the Matlab script.

## 4.7 Power Supply (N.S.)

The power supply was developed from four High Drain Samsung 30Q, 3000mAh 3.7V cells. This considered the power needs of the nodes as well as the available recapture rate observed in testing. For testing, our battery is a modular design connected with nickel plates and a PLA linked enclosure. This has the added advantage that additional cells can be added in later if needed. The battery was connected to the solar charger and demonstrated a successful charging process.

# 5 Technical Plan (N.S.)

The spring semester will mostly involve finalizing the hardware, the mesh network, and the gateway and console for the project. The fall semester has produced a variety of concepts and preliminary designs, so the spring will be focused on implementing them. The electronics need to be manufactured, assembled, and tested, the mesh network needs to be created and implemented, and the gateway node and console need to be able to communicate with each other and with sensor nodes. See the Gantt chart in Appendix 2 for more details about the scheduling of the remaining tasks.

## 5.1 Task I: PCB

Task I.I: Finalize PCB design.

The current PCB design will be refined and reworked to meet the capabilities of the manufacturer, JLCPCB. Their capabilities are listed on their website and should be implemented as design rules in Altium. The Altium design rule check tool will evaluate the design until there are no design rule violations, at which point the PCB will be ready to be manufactured. Lead: Ben; Assisting: Maxine.

Task I.II: Assemble PCBs.

Once PCBs are ordered and delivered, they will be tested for continuity and shorts. Once the boards’ manufacturing has been verified, they will be assembled according to the schematic, and will have their individual subsystems tested. This will be accomplished by first powering the Featherboard through USB to test the sensors, and then by connecting the solar panel to measure the current draw and charging current while operating from solar and battery power. Lead: Ben; Assisting: Maxine.

Task I.III: Integrate software and hardware.

The sensor systems and the power systems will be integrated with the microcontroller for data collection and power management. Mesh networking is not part of this task. Code will be written to operate the automatic boost converter bypass, and the function will be tested by using a variable lab-bench power supply to verify the over-voltage detection and protection. Code that reads data from sensors will be modified to accommodate new sensors and to improve formatting for increased RF bandwidth efficiency. The sensors will be tested to meet the specifications for precision. Lead: Ben; Assisting: Emanuel.

## 5.2 Task II: Console

Task II.I: Uploading from Console

An Arduino scripted console node will be made from a duplicate Featherboard and a WiFi shield enabling network connection. Code will be written to estable a private connection between the data channels on the server and the data queued in the console. The test shall be conducted from the device without user input as the console will not have user input to update the data sets. The design should be tested with data gathered from testing sensor nodes. Lead: Noah; Assisting: Maxine

Task II.II: Generate Node Comparison Controls

A Matlab visualization will be created for each data point at each sensor node to track its change over time independently. Controls shall be scripted to select and use Javascript to compare data channels across multiple nodes by generating the requested combination of data channels into a Matlab visualisation. The test shall be deemed successful if the webpage can correctly show a dynamic range of comparisons among both the same node and multiples of nodes. Lead: Noah

Task II.III: Integrate Console Pages into GitHub

All current HTML pages will be integrated within the plants-are-neat.github.io page. This shall be tested by testing nodes are live updating and that controls across pages as well as across node data channels still provide identical output whether they are based on the server or on a local client. This will enable both the source files for the design and web application to be present and viewable in the same location. Lead: Noah; Assisting: Maxine

Task II.IV: Alerts for Data Bounds

Controls will be scripted to allow the user to set bounds for any visualization that alerts the user if there is a threshold break off the bound. This will enable data on the console to not only be utilizable when viewing the page but away. The alerts will be scripted in Javascript and communication to the user sent in the form of an email. They will display what bound has been crossed and at what time. The test shall be conducted by producing a bound as well as data that goes through the bound. If the test is successful we should get communication reflecting the bound crossed and time it was crossed via email. Lead: Noah

Task II.V: Alerts for Data Breaks

Alerts will be scripted to alert the user if there is a break in the network. This will enable data on the console to alert the user if a channel isn’t updating so they can inspect the node. The alerts shall be scripted in Javascript and communication to the user sent in the form of an email. They will display what node has been lost and at what time it was last heard from. The test shall be conducted by producing a time signature break in the mesh and allowing the console to receive enough data that this node must no longer be communicating. Lead: Noah; Assisting: Sergio, Maxine

## 5.2 Task III: Mesh Network

Task III.I: Unique identification

For every single node in the field, there should be a single ID associated with that particular node. Upon failure from a node and having to restart, it is expected that it will have a protocol in place to reacquire its ID. To be done using past routing tables of nearby nodes and ISSR values to determine. No ID can be shared. Leads: Sergio and Maxine

Task III.II: Self Healing

The network should be able to function in the case of an error of a single node. Meaning that while the node is down, messages will be routed from a different route to reach its destination. Once the node comes back online, the node is seamlessly reconnected to the network and proceeds with its tasks. Leads: Sergio and Maxine

Task III.III: Message Forwarding

It is impossible for most nodes to be able to reach the gateway node. To this end, messages need to be forwarded to nodes in between the destination and the source. Protocol dictates that the node receiving the message has a routing table with the destination of the message in order to send it to the most appropriate node. Leads: Sergio and Maxine

Task III.IV: Routing Table

A routing table is a table meant to store the most efficient routes between this node and others. This is done so that the nodes don't have the memory burden of having to have the entire network stored in memory. The routing table needs to update in order to keep an up-to-date list with best routes to take into consideration things like nodes failing and weather conditions. Leads: Sergio and Maxine

Task III.V: Data Reporting

This task is to ensure that the individual nodes are able to report their findings back to the gateway node. Leads: Sergio and Maxine

Task III. VI: Sleep Scheduling

Designing a schedule based on internal microcontroller clocks, signal sending, or job completion. Decides when the device will go to sleep, when it will wake up, and for how long it stays awake. The main test will be a self-sustaining schedule of sleeping, waking, sending information, receiving information, and sleeping again in sync with other nodes, especially the mother node. Completed once the schedule achieves three successful and consecutive sleep-wake cycles. Lead: Emanuel; Assisting: Sergio, Maxine

# 6 Budget (B.L.)

The budget for this project’s R&D phase is $1000, with a grant of $500 to be provided by the department. The estimated budget for the project comes in at just under the grant amount, at $450.50. A detailed budget is shown below.

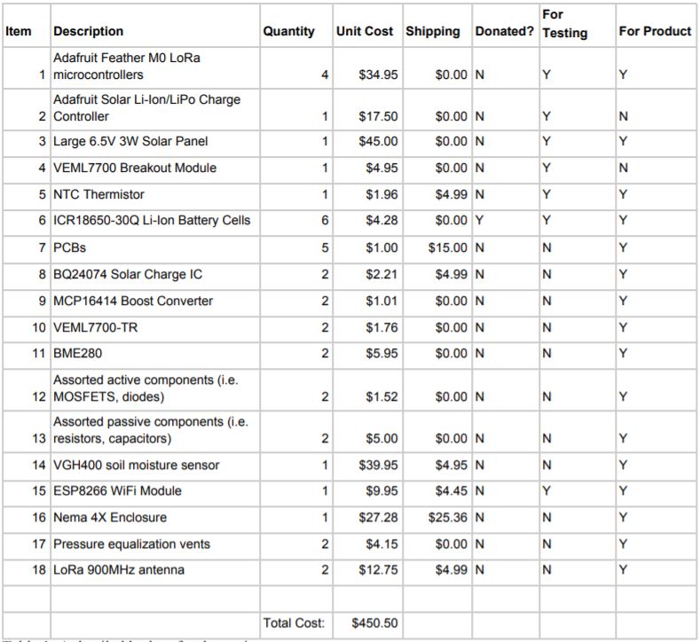
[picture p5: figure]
Word template Figure 1

Fig. 3. A detailed budget for the project.

Many of the components used for testing can be repurposed for use in the final product to save money. However, there are many components needed for the PCB for example that have not been ordered yet. All of the components, already purchased or not, are shown in the table above. Items 5, 8-13 are tabulated more specifically in appendix 3.

# 7 Appendix I – Engineering Requirements (B.L.)

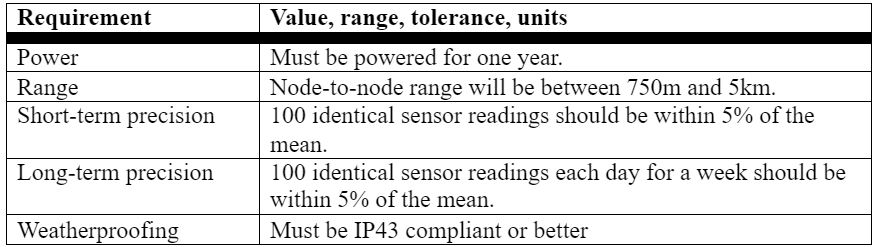
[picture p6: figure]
Word template Figure 1

Fig. 4. A list of the engineering requirements for this project.

Fig. 5. A list of engineering constraints for this project.

# 8 Appendix II – Gantt Chart (S.P.)

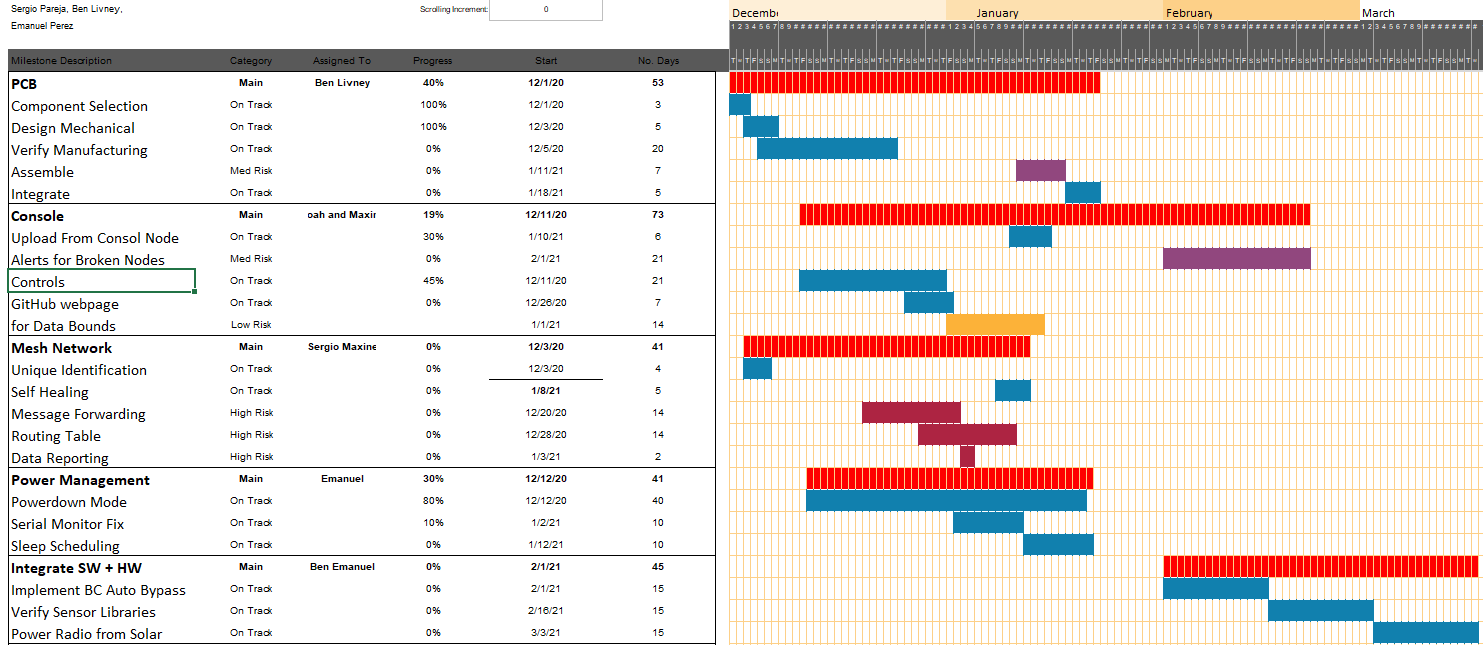
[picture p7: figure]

# 9 Appendix III – Additional Figures, References, Team Info (E.P.)

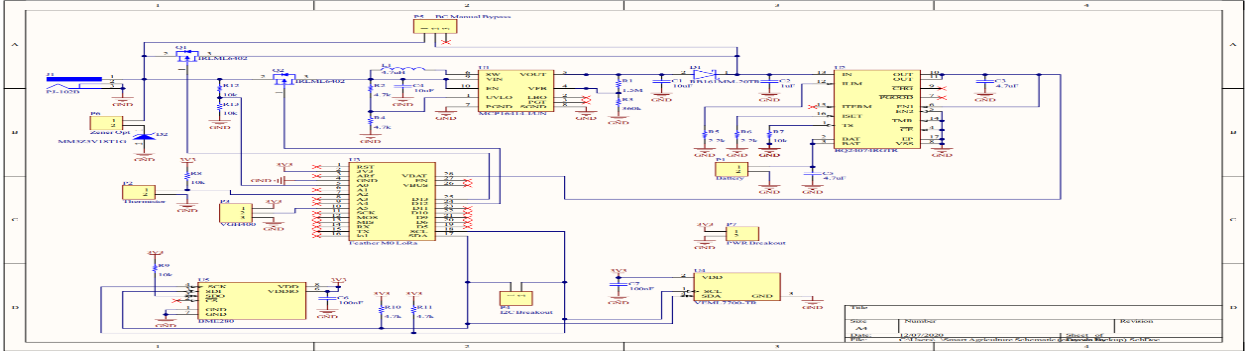
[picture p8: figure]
Word template Figure 1

Fig. 6. Schematics for the power electronics and sensor electronics

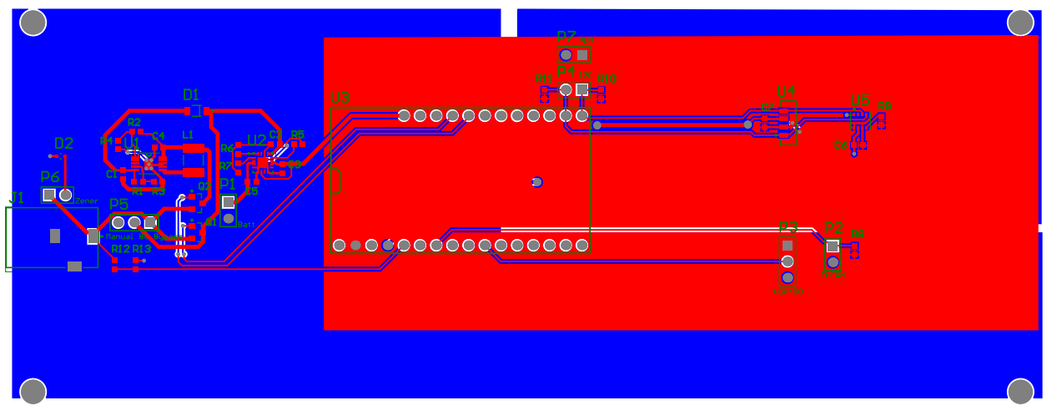
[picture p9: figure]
Word template Figure 1

Fig. 7. preliminary PCB layout.

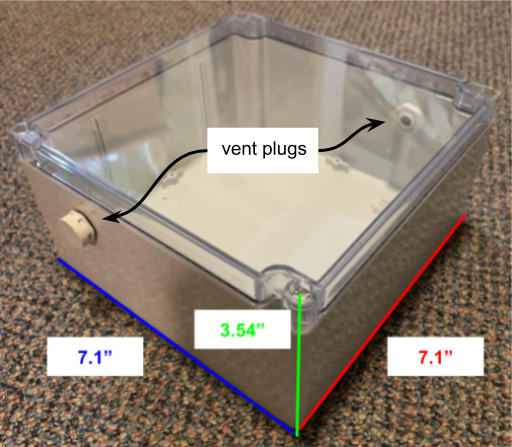
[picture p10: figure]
Word template Figure 1

Fig. 8. enclosure design

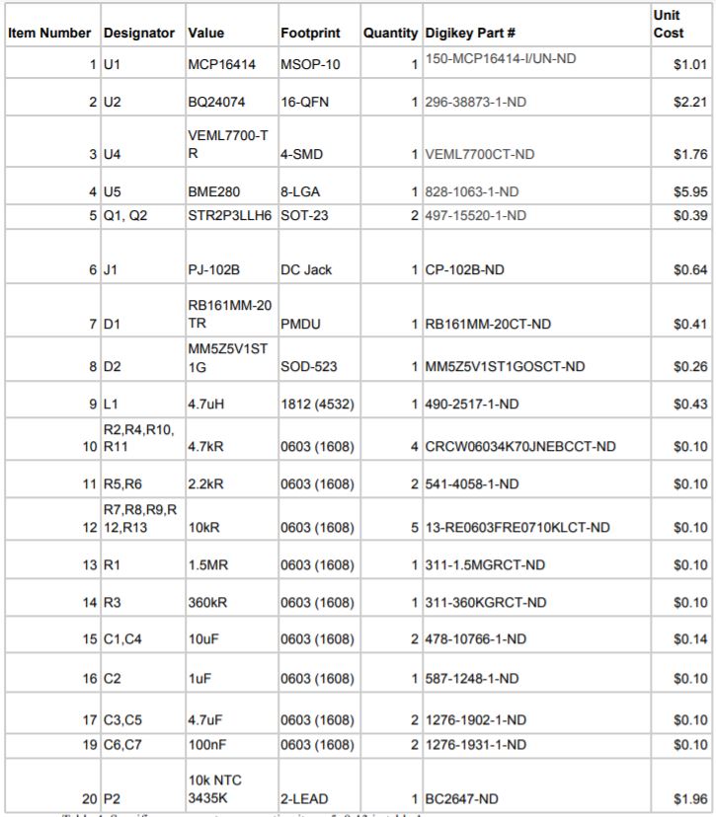
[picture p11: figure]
Word template Figure 1

Fig. 9. Budget Specifics

## 9.1 References

[1] “Almost 40 Percent of Worldwide Crops Lost to Diseases,” The Crop Site. [Online]. Available: https://thecropsite.com/articles/1202/almost-40-per-cent-of-worldwide-crops-lost-to-diseases/.

[2] "Sleeping Arduino - Part 1," Arduino, Zigbee and Embedded Development. [Online]. Available: http://donalmorrissey.blogspot.com/2010/04/putting-arduino-diecimila-to-sleep-part.html

[3] “Greenhouse Guardian: Environmental monitoring of greenhouse crops,” Bosch.IO, 17-Feb-2020. [Online]. Available: https://bosch.io/products/greenhouse-guardian/.

[4] “Homepage,” Sensoterra, 12-Oct-1970. [Online]. Available: https://www.sensoterra.com/.

[5] H. Solidpixels., “We bring innovative solutions to agriculture,” CleverFarm. [Online]. Available: https://www.cleverfarm.ag/.

## 9.2 Team Info

Ben Livney

845-642-0837

blivney@bu.edu

Maxine Loebs

631-702-5813

mloebs@bu.edu

Sergio Pareja

787-587-7420

sergio98@bu.edu

Emanuel Perez

832-267-8474

emperez@bu.edu

Noah Spahn

617-970-8255

nspahn@bu.edu

History of Team and Company:

The team started in mid September. We wanted to help one of society’s most important sectors, agriculture. A testament of our core values is in our name, Plants are Neat. Our lead market strategist, Ben, wanted our company’s name to follow our values of down to earth customer service while using simple solutions to solve modern problems. The goal of our company is to give farmers a reliable, economical way to survey their farmers without needing to traverse a huge landmass.

2 IEEE TRANSACTIONS ON XXXXXXXXXXXXXXXXXXXX, vol. #, no. #, MMMMMMMM 1996

AUTHOR: TITLE 3

ENG EC 463 – Team 27 – 1st Semester Report 1

8 ENG EC 463 – Team 27 – 1st Semester Report

ENG EC 463 – Team 27 – 1st Semester Report 9

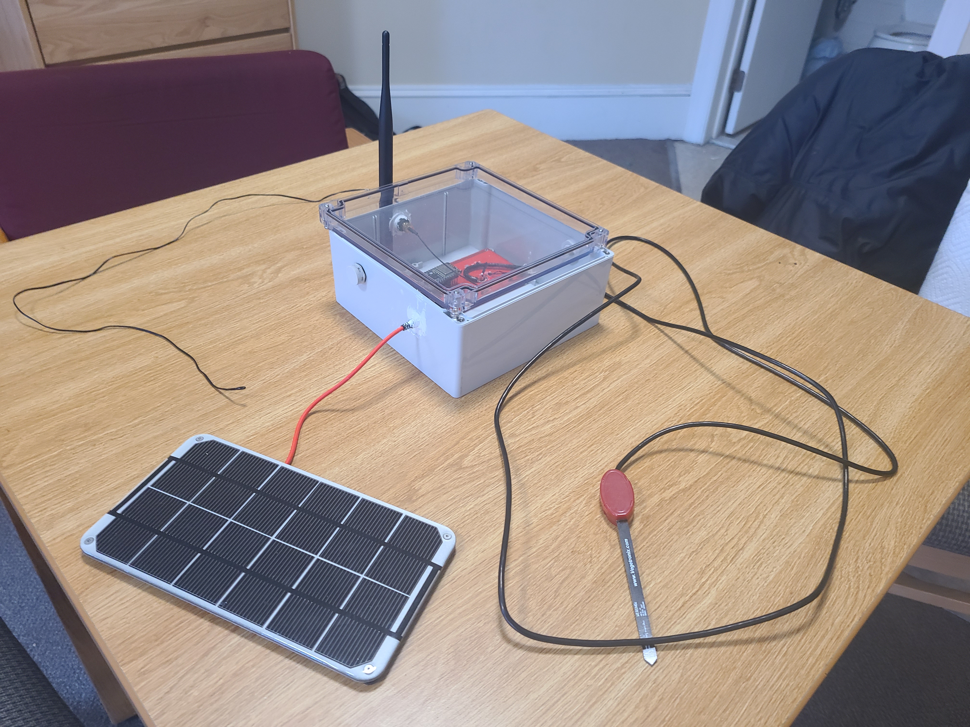
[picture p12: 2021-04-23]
assets/hardware1.jpg

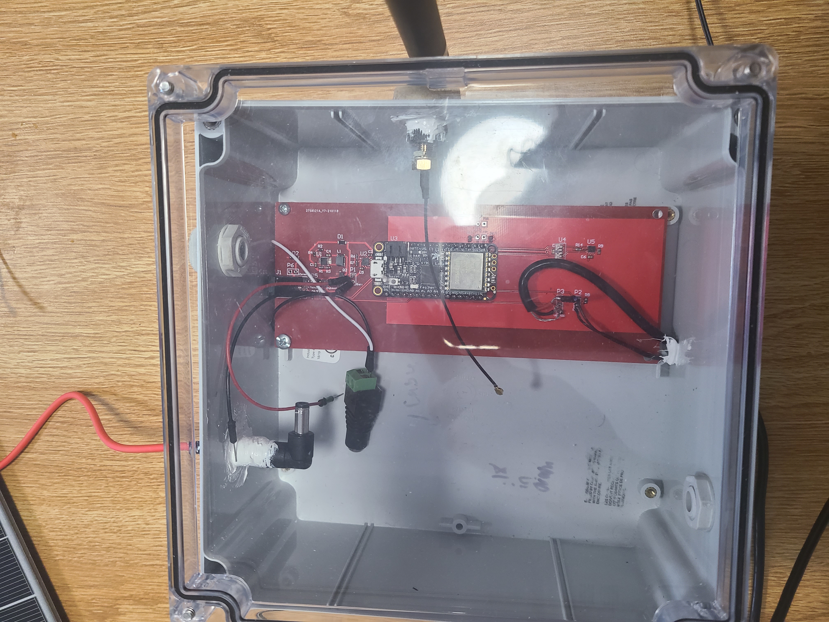
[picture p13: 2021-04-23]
assets/hardware3.jpg

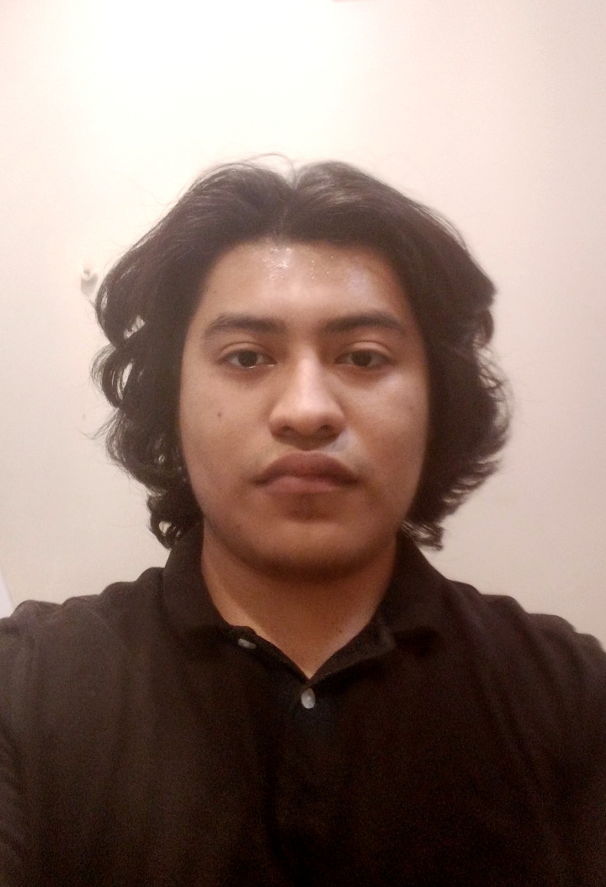
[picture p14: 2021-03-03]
images/emanuel.jpg

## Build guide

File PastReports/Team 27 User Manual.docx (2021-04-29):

# Boston University

# Electrical & Computer Engineering

# EC464 Capstone Senior Design Project

# User's Manual

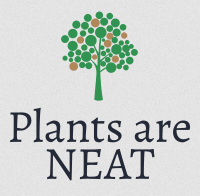
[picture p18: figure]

Plants are Neat

Submitted to:

Eugene Kolodenker

eugenek@bu.edu

by

Team # 27

Plants are Neat

Team Members

Ben Livney blivney@bu.edu

Maxine Loebs mloebs@bu.edu

Sergio Pareja sergio98@bu.edu

Emanuel Perez emperez@bu.edu

Noah Spahn nspahn@bu.edu

Submitted: 04/13/2021

#### 1.1.1.1 Plants are Neat

#### 1.1.1.2 Table of Contents

Plants are Neat 2

Table of Contents 2

Executive Summary 3

Introduction 4

System Overview and Installation 5

Overview block diagram 5

User interface 6

Physical description 6

Installation, setup, and support 7

Hardware 7

Software 7

Operation of the Project 9

Operating Mode 1: Normal Operation 9

Operating Mode 2: Abnormal Operations 10

Safety Issues 11

Technical Background 12

Relevant Engineering Standards 15

Cost Breakdown 16

Appendices 18

Appendix A - Specifications 18

Appendix B - Team Overview 18

Appendix C - Additional Figures 19

# 5 Executive Summary

Farming is paramount to society. Throughout history, as global populations have increased, farming methods have had to improve to keep up with growing demand. Today, the situation is no different – with more and more mouths to feed, farmers are looking to modernize their practice and adopt technologies that can help them boost crop yields, reduce waste, save money, and stay afloat among industrial-scale agricultural corporations. To address this need, we will be developing a fully-functional

agricultural sensor network, which reports data about specific locations on the farm back to the user in the comfort of their farmhouse. We have come up with a detailed plan to realize our design. The backbone of our final product is our sensor nodes. These will contain our selected sensors, a microcontroller equipped with a radio transceiver, and the required hardware to supply power to all of the electronics inside. All of the components will be put into a weatherproof enclosure. All of these nodes will be connected together in a scalable mesh network. The data from all of the nodes will be pooled into a single gateway node, which will then send compiled data to our web console. Our web console will present this live data in a neat, readable format. There are other agricultural sensor networks on the market, but our product will include a number of innovative features that make it stand out, such as energy harvesting, and the use of a wide variety of sensors to paint a full picture of many conditions out in the field.

# 6 Introduction

In recent years, farmers have been embracing technology to supplement and/or replace more traditional farming methods in order to increase crop yields, lower the cost of production, reduce waste, and – in the case of smaller, local farmers – remain profitable and competitive in a market that is dominated by large-scale agricultural corporations.

As such, we have created an agricultural sensor network to help accomplish all of these things. The network allows the farmer to be aware of the conditions at any location on their farm at which an individual sensor node is placed, all without having to actually set foot out into the field, as the data is available to view on a web console. This saves time and money. The farmer doesn’t have to drive around the farm themself to check on things, or pay people to do the same. Some farms – even those owned by small farmers – are massive in size, so checking up on areas of the farm could become quite time-consuming, even when done only once a day. Having insight into the current conditions around the farm additionally allows the farmer to save money by being able to better distribute resources. For example, the device is equipped with a soil moisture sensor. By monitoring soil moisture, the farmer can in turn adjust how much they are watering different areas of their fields, preventing overwatering and in hand saving money. With knowledge of field conditions, the farmer can make adjustments to ensure ideal conditions for achieving the most successful crop, and thus achieve higher profits.

The sensor nodes feature solar energy harvesting electronics to maintain power for up to a year continuously. Intelligent power path management will maintain power to the sensor node by managing available solar power and power from a backup li-ion battery. The sensor nodes are capable of measuring ambient temperature, humidity, ambient light, soil moisture, and soil temperature, and can transmit data wirelessly using the LoRa RF protocol. The network, when installed correctly, has indefinite range if enough nodes are available, and does not require cell service or Wi-Fi to operate. The network is self-healing, so if a node malfunctions, the network will discover this and notify the user. A gateway node collects all of the data and displays it on a website to easily view data from all nodes.

# 7 System Overview and Installation

## 7.1 Overview block diagram

Each sensor node is outfitted with a solar energy harvesting system incorporating a small photovoltaic (PV) module and power electronics to maintain power for at least one year. Nodes are equipped with a 3W 6.5V PV module capable of providing a maximum of 460mA in high light conditions. In order to not drive the module too hard, a maximum battery charging current of 400mA is set by the battery charger. For low light conditions, a low-power boost converter increases the PV voltages above 1V up to 5V to operate the microcontroller correctly and to power the sensors.

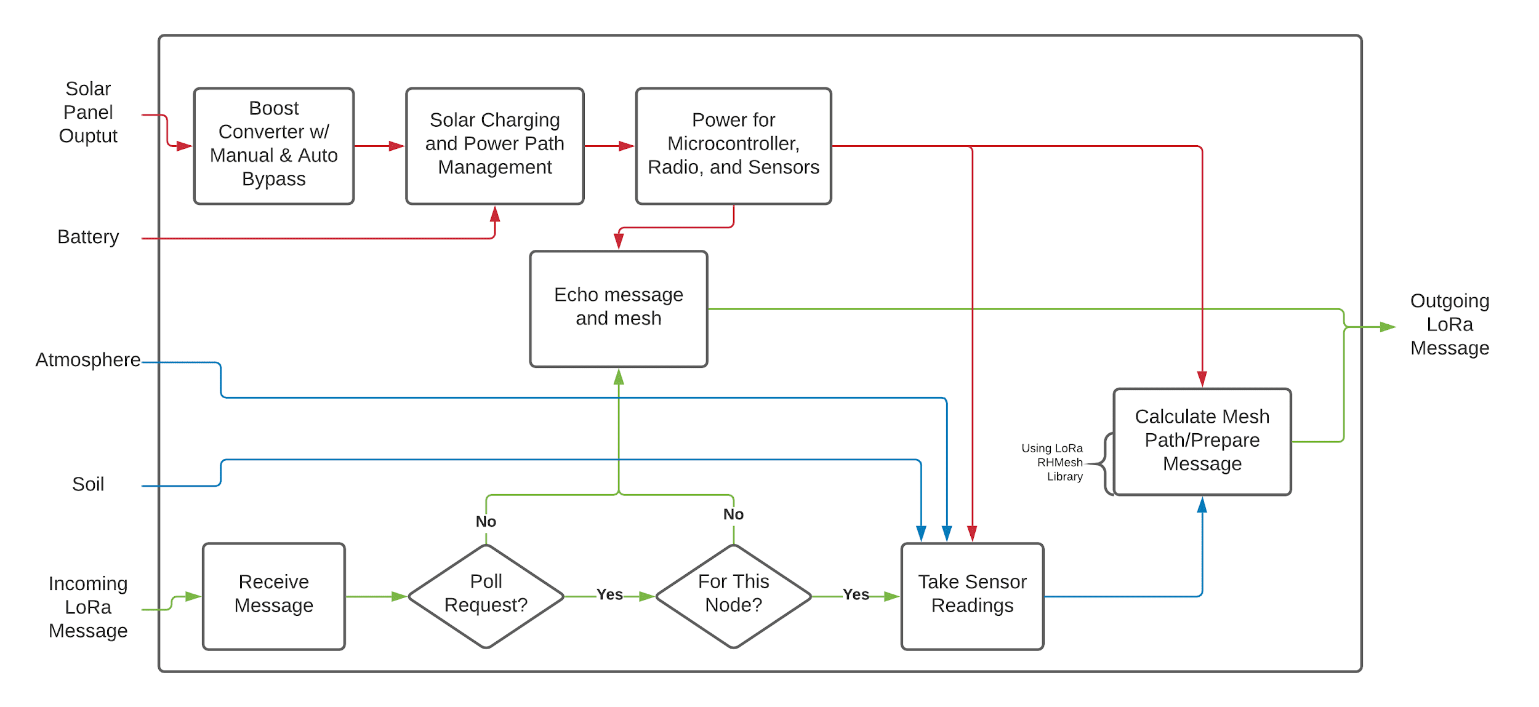
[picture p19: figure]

Figure 1: A functional analysis of a sensor node describing power flow, sensor operation, and LoRa mesh networking.

The LoRa communication protocol allows for wireless communication and mesh networking between LoRa-enabled devices using a tunable 900MHz carrier signal without the need for cell service, Wi-Fi, or Bluetooth capabilities. As shown in Figure 1, each sensor node listens for incoming LoRa messages, either from the gateway node or from other sensor nodes. If the incoming message is not a poll request, meaning the message contains sensor readings, the sensor node uses the established mesh protocol using LoRa to repeat that message, sending it closer to the gateway node for analysis. If the incoming message is a poll request, the sensor node checks if it is polling itself, in which case it takes sensor readings and sends them to the mesh network. Otherwise, it repeats the poll request so that other nodes out of range of the gateway can receive it.

The gateway node sends poll requests at regular intervals to the mesh network for data from specific sensor nodes. As described above, the sensor nodes echo the poll request until it reaches its destination, at which point the data is sent and echoed back. If the gateway node receives a response before a timeout, it pushes it to the web console for processing using a Node.js batch file. If no response is received before the timeout, the gateway node pushes a notification to check the status of the requested node. Since the network should be installed such that every node is in range of multiple other nodes, there will be many paths from the gateway to any requested node. Thus, if a timeout occurs, the gateway will know that the requested node is at fault and not some other sensor node.

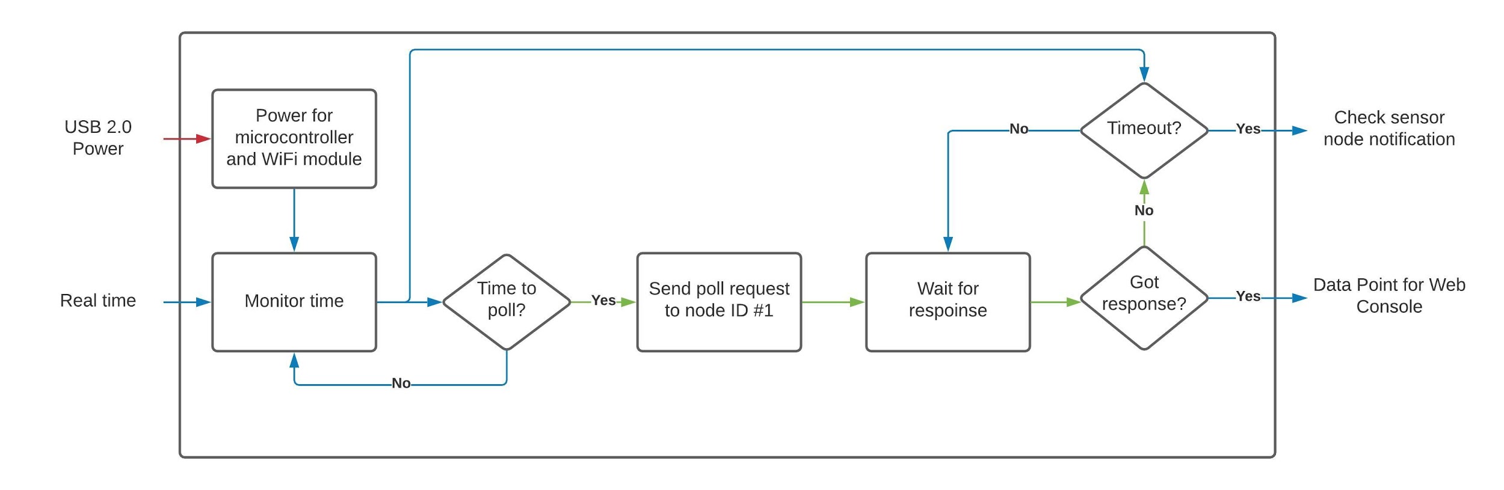
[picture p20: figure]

Figure 2: A functional analysis of the gateway node describing poll requests, responses, and interaction with the web console.

## 7.2 User interface

The user interface of our product is made up of a webpage based client that reports data and notification thresholds to the user. The system uses a webpage integrated with javascript to pull data from the thingspeak channel and display the data for requested nodes at the given time. The nodes can be toggled between on the page to display different graphs. Thresholds for notifications can be viewed within the gauge values.

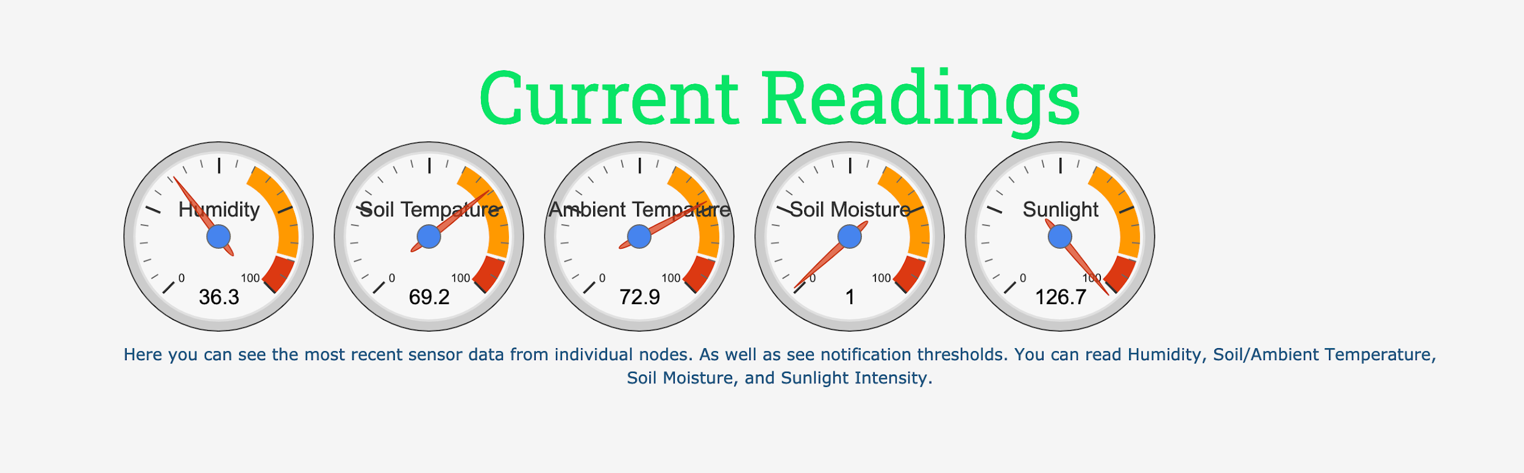
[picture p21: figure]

Figure 3: A screenshot of the automatically updating dials on the web console that the user can view to see the data in real time.

## 7.2.1 Physical description

The electronics of our sensor node are housed in a NEMA 4X compliant enclosure. The enclosure measures 7.1 x 7.1 x 3.54 inches. It has a removable, clear plastic cover attached with screws. A gasket provides a waterproof seal between the cover and the rest of the enclosure. Attached are two vent plugs which allow for pressure equalization. Sensors for soil moisture and soil temperature extend out of the enclosure to be placed into the ground. The solar panel cable also feeds into the enclosure. The solar panel should be placed to the side of the enclosure, so it doesn’t cast a shadow and prevent accurate readings of the ambient light sensor. The antenna also is external, to prevent any sort of attenuating of the signal.The through holes drilled into the sides have all been sealed with a marine-grade sealant to keep the enclosure completely weatherproof.

The node is secured to the ground with simple ground stakes, similar to what you’d use to secure a tent. They are places in holes that extend through to the bottom of the enclosure, external to the part that is weatherproof.

Figure 4a and b: Pictures of the enclosure of the sensor node.

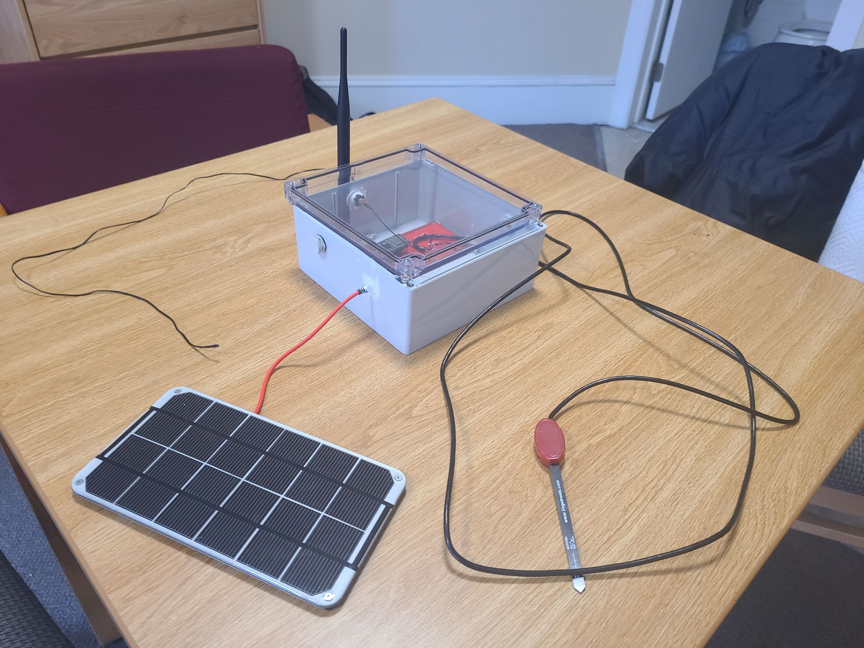
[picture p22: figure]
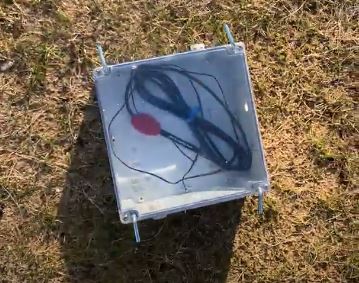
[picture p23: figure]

## 7.3 Installation, setup, and support

## 7.3.1 Hardware

Installation of hardware will require as many nodes as needed, a micro-usb to usb cable, and any windows computer. The nodes will require four (4) metal spikes that come with each node. Place the enclosure in the desired spot and drive each spike through the slots on the edges of the enclosure and through the ground with a hammer. Drive the soil moisture/temperature sensor into the ground and ensure the humidity sensor is above ground. Make sure that the solar panel is facing up towards the sun. Repeat the process for each node, noting that each node should be no further away than three (3) kilometers away from any other node. If the nodes lack line of sight it is important to place them much closer. The on-board microprocessors already have the code flashed on to them, therefore once nodes are installed they will automatically start-up and work on their own. Then proceed to connect the mothernode with the micro-usb and the computer with the USB. If the on-board LED’s light up, then the installation of the mothernode was successful.

## 7.3.2 Software

The user interface can be found on https://plants-are-neat.github.io/, no set-up required. Email automatically sends upon reaching thresholds.

A stable internet connection and a computer are both required to run the network.

Windows

Installing with a Windows machine will require all relevant files (PANinstall.bat, runMESH.bat, Serial.js) and NODE js to be fully installed. After all files have been downloaded from the git, simply make sure the three files are in the same directory and double click the PANinstall.bat file to run it. This batch file is responsible for downloading the dependencies needed to run the Serial.js file. Then running the runMESH.bat file will initialize the connection between mothernode and the computer. It is important to note that the computer needs to be on to be updating the information on the website. Lastly, make sure that no other programs are using the serial connection, the serial connection cannot be shared between programs and may cause the software to crash and exit execution.

Other

Installing with a machine other than a Windows operating system will require all relevant files (Serial.js) and NODE js to be fully installed. Open the command prompt and input the following commands:

npm install thingspeakclient

npm install serialport

npm install prompt-sync

These commands will download all NODE.js dependencies needed to run the Serial.js. To run initialize the connection between the mothernode and the computer input the command:

node Serial.js

It is important to note that the command line needs to be in the same directory as the Serial file. Also important to note that the computer needs to be on to be updating the information on the website. Lastly, make sure that no other programs are using the serial connection, the serial connection cannot be shared between programs and may cause the software to crash and exit execution.

# 8 Operation of the Project

## 8.1 Operating Mode 1: Normal Operation

Operating Mode:

The following instructions are for the mother node to work properly.

Figure 5: The relevant installation files.

After setup and installation is finished. The next step will be running the runMESH.bat (as shown above) via double clicking the file. Make sure everything is located in the same directory. The user interface would be displayed on screen (as shown below). The program will display all serial connected devices. Please select the correct COM option corresponding to COM that is used for the mother node. After the selection, the program will start running the SerialTest.js.

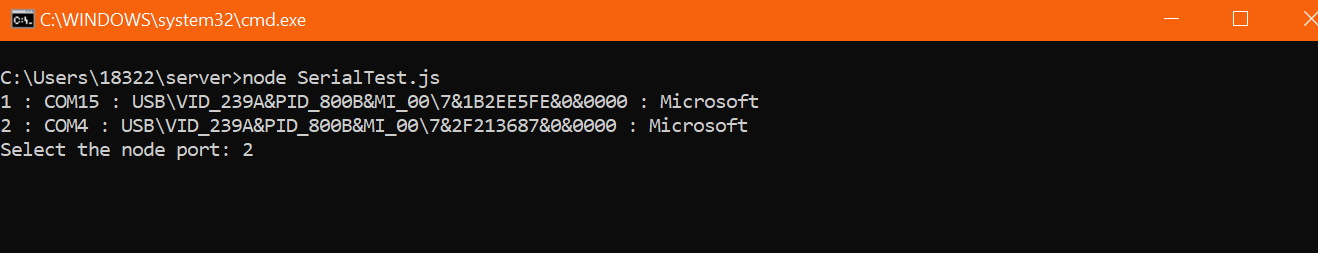
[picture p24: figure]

Figure 6: The command prompt while setting up the Node.js connection

Once the outer nodes are installed correctly, the console will start receiving messages (data) from them. If the data received is valid, a message of being sent would show up (as shown below). If the console does not print, “update successfully. Entry number was: #”, check abnormal results section for troubleshooting solutions. If the frequency of the outer node is high (every five seconds), the program will update the server sequentially via first-in first-out behavior. The remote server (website) will display the changes every ten seconds.

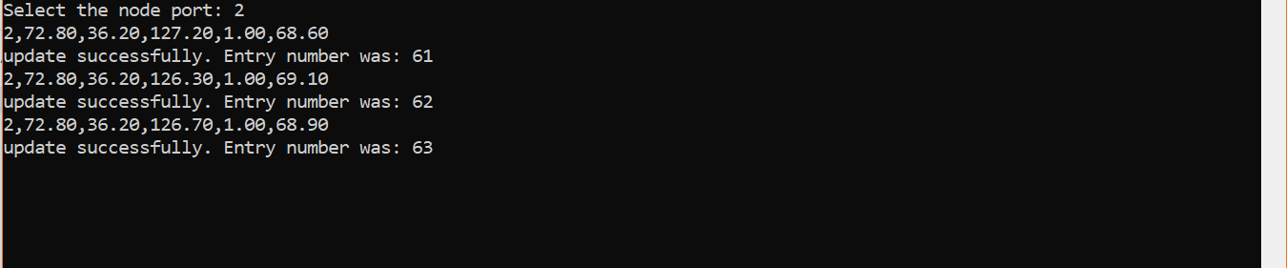
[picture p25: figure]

Figure 7: A screenshot of the command prompt while data is streaming in.

After the console message, the data will be sorted out in the website to match it’s format like the following:

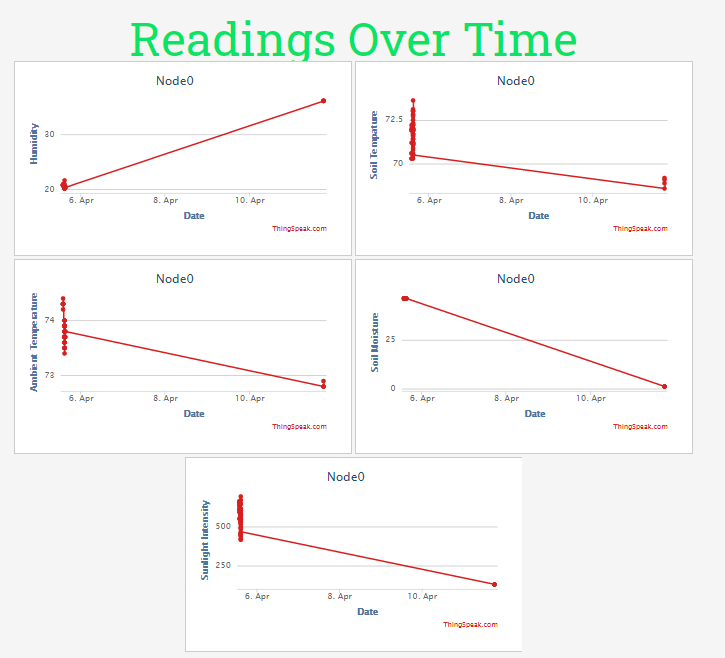
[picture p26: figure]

Figure 8: Live plots of data streaming in for a sensor node.

Other than running the program in the background, no further actions are needed to properly request data, send data, and update the server.

Outer Node Operating Mode:

After setup and installation is finished for the outer microcontroller (node), the outer node will need to be powered via battery, usb, or wall. Afterwards, the node will not need any further steps to work properly. Set the microcontroller in the desired location to collect sensor data. During installation, the device’s data collection frequency can be customized (how long it stays asleep) and sent to the mother node.

Exit (Stop) Operating Mode:

To exit and stop the program, press Ctrl + C (at the same time). The program will ask if you would like to terminate the batch job, type Y and press enter to complete the exit. The image below illustrates the procedure.

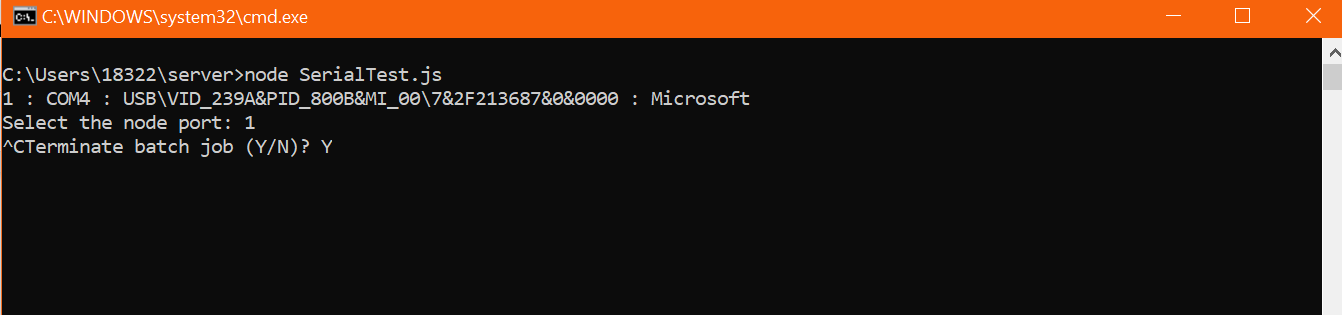
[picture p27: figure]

Figure 9: The command prompt when exiting the data streaming program.

## 8.2 Operating Mode 2: Abnormal Operations

Abnormal results:

Figure 10: Abnormal data.

Above is an example of abnormal data caused by the outer node having broken sensors (or installed incorrectly). The mother node will receive and display the message to the console, but will not send the data to the website. The threshold of what the program considers abnormal can be changed in the SerialTest.js file to match the commonality of the

The problem is rooted either by a faulty sensor or a faulty device. The difference can be seen in the data collected. The example above illustrates incorrect data for all sensors, but if only one is the issue, then reinstalling a new sensor will be the optimal fix. The problem can be solved by installing the sensors correctly or replacing the broken node with a new node.

## 8.3 Safety Issues

There are no serious safety issues inherent to our project. The greatest concern, which we have put in a lot of effort to prevent, is the chance of water getting in contact with active electronics. We have completely waterproofed our enclosure to avoid any chance of this happening. Of course, it is the responsibility of the user to make sure that water does not enter the enclosure when the cover is off. The only other possible hazard that comes to mind is the possibility to trip over the nodes when they are in the ground! It may be a good idea to mark the locations with some sort of flag to make the placement a bit more conspicuous.

# 9 Technical Background

4.1 Hardware Component

The physical electronics for this project consist of sensors to gather meaningful data, a LoRa-equipped microcontroller to poll the sensors and access the mesh network, and solar charging and power path management electronics to effectively harvest solar energy to power the project for upwards of one year continuously.

4.1.1 Sensors

The project features a mix of analog and digital sensors. The analog sensors operate by changing an electronic property in response to varying nonelectronic conditions. For example, the soil temperature sensor is a thermistor, whose resistance changes according to temperature, and the soil moisture sensor produces a varying output voltage in response to changing volumetric water content. The digital sensors use the I²C protocol, and are addressed by the LoRa-equipped microcontroller using two data lines. The chosen microcontroller is a FeatherBoard with LoRa from Adafruit.

4.1.2 Power

A solar panel is used to harvest solar energy in order to power the electronics. The BQ24074 IC is responsible for managing power delivery and regulation. When solar power is available, it delivers power to the electronics while also charging a backup battery, a 4-cell li-ion 12000mAh battery. When solar power is available but weak, it will not charge the battery but it will power the electronics. When solar power is not available, the battery will start to power the electronics until solar power becomes available again.

4.2 Software Component

For software components we chose to use Arduino’s IDE for its simplicity judged against the C++/C the microprocessors would normally use. For libraries we used RadioHead.h, a library built around these LoRa equipped microprocessors that facilitate communication between boards. We also decided to use NODE js because of its event-driven and non-blocking nature. Meaning that the code does not run from line to line but is constantly executing different commands from different functions simultaneously which is useful when it requires to react to real time events. Lastly, we made batch files for ease-of-use for the user. The batch files run commands based on the Windows operating system to install all NODE js dependencies and another batch file to execute the NODE js code.

4.2.1 LoRa & Mesh Network

We chose to use LoRa for our RF protocol. Operating on the 900MHz ISM band, it does not require a license. It is very long range with line-of-sight and consumes very little power. We set up our nodes to communicate in what is known as a mesh network. Our network consists of several sensor nodes as well as a gateway node which polls individual sensor nodes for data. In this mesh network, the sensor nodes all communicate with each other as well as the gateway, rather than simple two-way communication between each individual sensor node and the gateway. This has a number of benefits. Poll requests and data to be sent back to the gateway can travel much further distances. Messages can bounce from node to node until reaching the target destination, so as long as intermediate nodes are available, a message can get to a very distant node from the gateway and vice versa. Moreover, the routes from source to target are automatically routed. This means that if a certain node acting as an intermediary were to break and could not receive a signal, a new path could be found automatically if other nodes were in range. This level of robustness is important, especially if farms were going to utilize many nodes, as one node breaking would not knock out the entire network. The LoRa protocol and mesh network were established using Arduino libraries compatible with our Adafruit Feather M0 boards.

4.2.2 Sleep Protocol

To minimize energy consumption, the outer node periodically goes to sleep every X (determined by the user during installation) minutes. The use of Adafruit SleepyDog library to robustly put the device into lowest power consuming mode. The library uses the device’s power mode (specifically SLEEP_MODE_PWR_DOWN) to shut down all unessential functions. The library uses the device’s watchdog timer functions to wake up every 8 seconds. As a result, the device repeatedly goes to sleep till it matches the user’s input. Afterwards, the device carries on to its main function.

4.2.3 Networking to Web Console

Since different microprocessors have different architectures that complicates board-to-board communication, we decided it would be best to communicate directly to the computer using a micro-usb to usb cable. The cable establishes a serial connection between the computer and the mothernode. The microprocessor then can send bits of information using its built in serial commands to display data. The NODE js code reads from the port in order to display what was picked up and uses ThingSpeak’s own library to send that information to the relevant channels on the website.

4.2.4 Web Console and User Interface

In order to demonstrate the WebApp visualization portion of the client’s needs, we utilize a Matlab analysis script, and the ThingSpeak IoT tool to upload data and analyze the uploaded data into a visualization. Data is uploaded from the gateway node via a USB serial connection, and is analyzed by a Matlab script operating within ThingSpeak. The frequency of data collection is programmable and currently set to poll the sensor nodes every 15 minutes. The visualization is done through ThingSpeak with a server-based Matlab script. The live data is displayed within the plants-are-neat.github.io page. Live-updating dials and graphs allow the user to view live data in real time using different formats.

4.3 Physical Component

The most important consideration for choosing an enclosure to house our electronics was weatherproofing. The sensor nodes will be out in a field, so depending on the local climate they can be subjected to hazards such as heavy rains, windblown dust, mud, or ice. As such, we decided on an enclosure that is NEMA 4X compliant, meaning that it is watertight, protects against fallen and windblown dirt and dust, undamaged by the formation of ice, and corrosion-proof. We inserted pressure-equalizing vent plugs on opposite sides of the enclosure, which maintain this NEMA 4X compliance. This allows for accurate readings from out sensors, as well as added protection against condensation accumulation. Through-holes were drilled for our external antenna, the solar panel cable, and the soil moisture and temperature sensors. These holes were sealed with a marine-grade polyurethane sealant that keeps any water from entering the enclosure. To secure the node to ground, four holes were drilled next to the cover screws, which extend through to the bottom. These holes exist outside of the part of the enclosure that is weatherproof. We chose to use simple garden stakes, which are easily inserted into these holes.

# 10 Relevant Engineering Standards

This project uses the feather M0 LoRa equipped model from Adafruit. This product already is compliant with many IEEE (Institute of Electrical and Electronics Engineers) and United States government agencies like the FCC (Federal Communications Commission). The FCC controls communications for the radio, the FCC ID number for the product is 2ASEORFM95C. The tests constructed by Adafruit shows that they comply with the following FCC standards:

FCC 47 CFR Part 2, Subpart J

FCC 47 CFR Part 15, Subpart C

KDB 174176 D01 Line Conducted FAQ v01r01

ANSI C63.10-2013

KDB 558074 D01 15.247 Meas Guidance v05

The frequency the radio can reach is 945MHz so it’s within the 0-3GHz set by the IEEE C95.2-2018 standard. The frequency we used, 915MHz, is in compliance with the NTIA and should not interfere with any other radio signals that may be used. Important to note, these standards are, for the most part, for the United States and not liable to be used in other places that are not part of the mainland United States or any of its territories.

Our enclosure has a NEMA 4X waterproofing standard, meaning that absolutely no circulating particles such as dust or lint may get into the enclosure. Dust or lint settling on top of the box is also no issue for the enclosure. It can also resist being ‘hosed-down’ without letting any liquid in. Lastly, it can also easily resist objects thrown or dropped onto it such as dirt. The equivalent for the product using the IP standards (Ingress Protection Code) would be IP64 since it allows no dust to enter the enclosure and no splashes of water to get in, but no tests were conducted using water jets so a higher rating cannot be guaranteed.

The solar panel and the battery both use the IEEE 1562-2007 standard. Both the size and working currents and voltages don’t go above 1 ampere or 5 volts. They both work on powering the microcontroller with adequate power and timing and do not interfere with each other thanks to the on PCB wiring.

The PCB itself was measured against IPC standards (Institute for Interconnecting and Packaging Electronic Circuits). The PCB falls under class-1 of the standard since it is a consumer product with no ‘hard’ requirements to be running without fail. The PCBs are not meant to be tampered with after sale and coupled with the resistant enclosure the only standard necessary to meet was IPC-2221, IPC-2221B standard and the IPC-9592 , it is a class-1 pcb with a level-1 wiring.

The software was done using standard coding practices. Meaning there are no variable names that do not directly relate with the purpose of the variable. All lines are indented using the ‘tab’ key. Each line that requires explanation has either a comment or a block comment explaining the process. Lastly, the general code structure goes library or dependencies inclusions, global variable declarations, functions, and then user defined functions. Each function also starts off with variables unless it is declared later on for the sake of efficiency running the program.

# 11 Cost Breakdown

The cost of each sensor node may seem daunting at first glance. This proposed cost breakdown is for the next design revision of the product, the beta version. The cost can be significantly reduced for the mass-manufactured version by selecting less expensive sensors and by integrating the LoRa capabilities and microcontroller onto a single PCB with all other electronics. The sensors chosen for the alpha version, and the sensors listed here in the beta version, are some of the easiest to use sensors on the market. As such, their price is very high. Selecting less expensive, but less intuitive sensors could bring the price down. Additionally, the LoRa FeatherBoard microcontroller board has many additional unnecessary features for this product. Taking only the LoRa module and a more bare-bones microcontroller can bring the cost down significantly. This price estimate is also for single units, and the price will decrease for bulk ordering.

Project Costs for Production of Sensor Node Beta
Item | Quantity | Description | Unit Cost | Extended Cost
1 | 1 | LoRa FeatherBoard microcontroller | $34.95 | $34.95
2 | 1 | Large 6.5V 3W solar panel | $45.00 | $45.00
3 | 4 | Sensors | $12.41 | $49.62
4 | 1 | All electronics (i.e ICs and passives) | $9.74 | $9.74
5 | 1 | LoRa antenna | $12.75 | $12.75
6 | 4 | Li-ion battery cells | $4.28 | $17.12
7 | 1 | PCB | $4.00 | $4.00
8 | 1 | Nema 4x enclosure and vents | $31.43 | $31.43
Sensor Node Beta Total Cost | | | | $204.61

Project Costs for Production of Gateway Node Beta
Item | Quantity | Description | Unit Cost | Extended Cost
1 | 1 | LoRa FeatherBoard Microcontroller | $34.95 | $34.95
2 | 1 | LoRa Antenna | $12.75 | $12.75
3 | 1 | Enclosure | $5 | $5
Gateway Node Beta Total Cost | | | | $52.70

# 12 Appendices

## 12.1 Appendix A - Specifications

User Requirements | Solution Rating (0-10) | Qualitative
View Weather Data from anywhere | 9 | Website has mobile as well as well as desktop compatibility
Modularity of Solution | 10 | System communicates sensor data with modular data center
Ease of Setup | 7 | Semi-automated however some technical setup
Notifications | 7 | Email notifications including node
Enclosure Weatherproofing | 10 | IP43 compliant
Node Self Sufficiency | 9 | Hypothetical ability to self sustain indefinitely
Communication Range | 8 | Testing suggested a range of 1km between each node

## 12.2 Appendix B - Team Overview

Ben Livney

845-642-0837

blivney@bu.edu

Maxine Loebs

631-702-5813

mloebs@bu.edu

Sergio Pareja

787-587-7420

sergio98@bu.edu

Emanuel Perez

832-267-8474

emperez@bu.edu

Noah Spahn

617-970-8255

nspahn@bu.edu

History of Team and Company:

The team started in mid September. We wanted to help one of society’s most important sectors, agriculture. A testament of our core values is in our name, Plants are Neat. Our lead market strategist, Ben, wanted our company’s name to follow our values of down to earth customer service while using simple solutions to solve modern problems. The goal of our company is to give farmers a reliable, economical way to survey their farmers without needing to traverse a multi thousand acre landmass.

## 12.3 Appendix C - Additional Figures

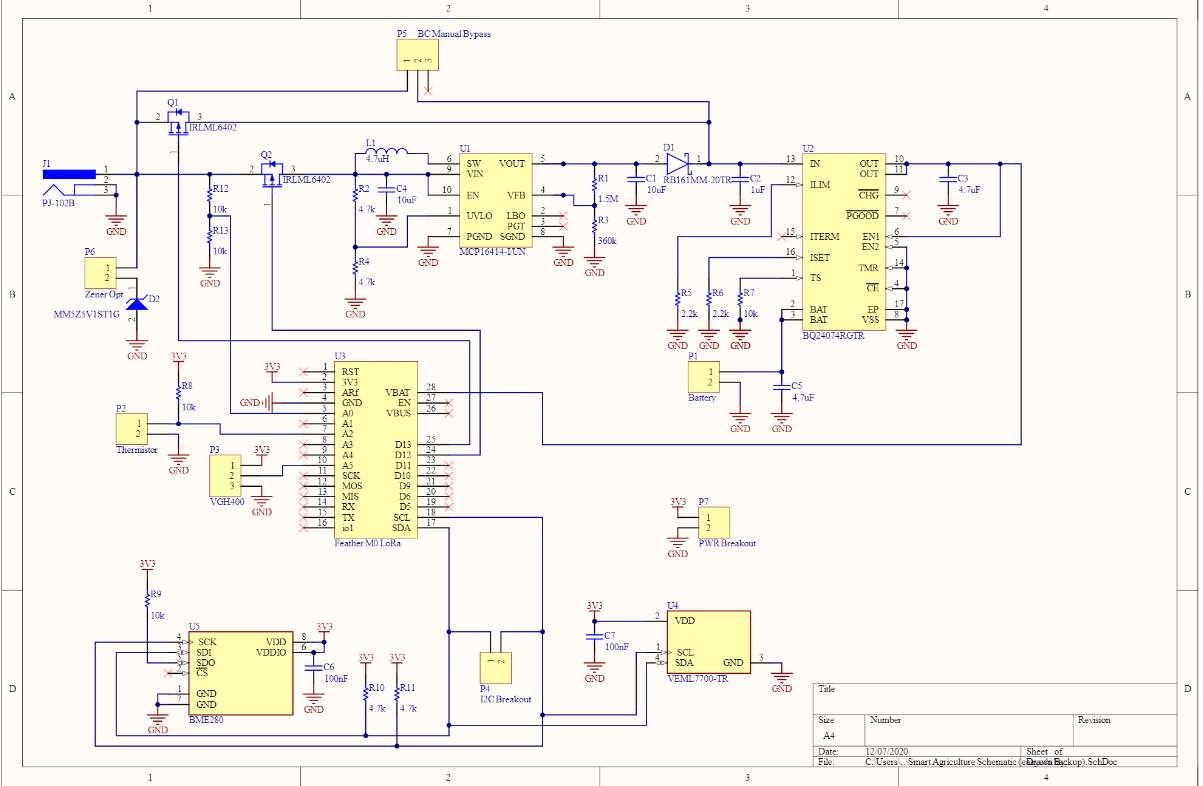
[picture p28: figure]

Figure 11: A full schematic.

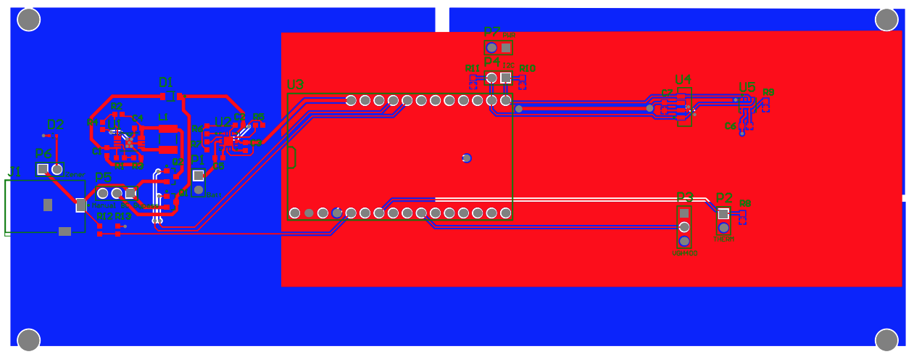
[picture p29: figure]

Figure 2: A rendering of the PCB layout.

Team 27 (Smart Agriculture Network: Plants Are Neat) April 13, 2021

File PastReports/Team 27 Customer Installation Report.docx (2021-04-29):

Memo


Senior Design

ENG EC 463

To: Professors Pisano, Osama, and Hirsch

From: Ben Livney, Maxine Loebs, Sergio Pareja, Emanuel Perez, Noah Spahn

Team: 27 - Plants are Neat

Date: 04/30/21

Subject: Customer Installation Report

1.0 Details of Meeting

We met with our client Eugene on Saturday, April 17th at 2:30pm over zoom (all members were present). The installation, which was completely virtual, lasted around 30 minutes. We were able to demo our project successfully despite doing everything online. Eugene was impressed with our work, and offered some suggestions on how to be more successful on ECE day.

2.0 Requirements

2.1 Requirements for the project are listed in the table below. With Eugene, we went through them and he was impressed with our ability to meet the requirements. Some requirements were modified from the original project definition, which is noted below as well.

Requirement | Original | Eliminated/Skipped | Final | Modified | Description
Power | X | | X | | Must be powered for one year.
Range | | | X | X | Node-to-node range will be between 500m and 5km (originally 750m to 5km).
Self-Healing | X | | X | | Broken nodes should be identified and a new route should be discovered to circumvent broken the node.
Precision & Data Upload | X | | X | | Out-of-range data should be ignored, data should be presented on console for interpretation.
Weatherproof | X | | X | X | Must be NEMA4X compliant or better (originally IP43 or better).

3.0 Assessment of Installation

All in all, our client was satisfied with our progress this semester and the final product that we presented to him. At the time of our presentation, we had only been running our network for a short amount of time, so the amount of data shown on the graphs on our webpage was limited. He suggested that for ECE day, we let our system run for quite a while beforehand to be able to view a nice trend in our data. Since we only had one node in our system outfitted with sensors, we also only had one display page on our website. He suggested that we still make pages for at least one other node so a system to toggle between the displayed data of different nodes could be demonstrated. Eugene was understanding of the fact that our budget limited us in how many nodes we could fully outfit with sensors, power management, etc.

4.0 Customer Acceptance

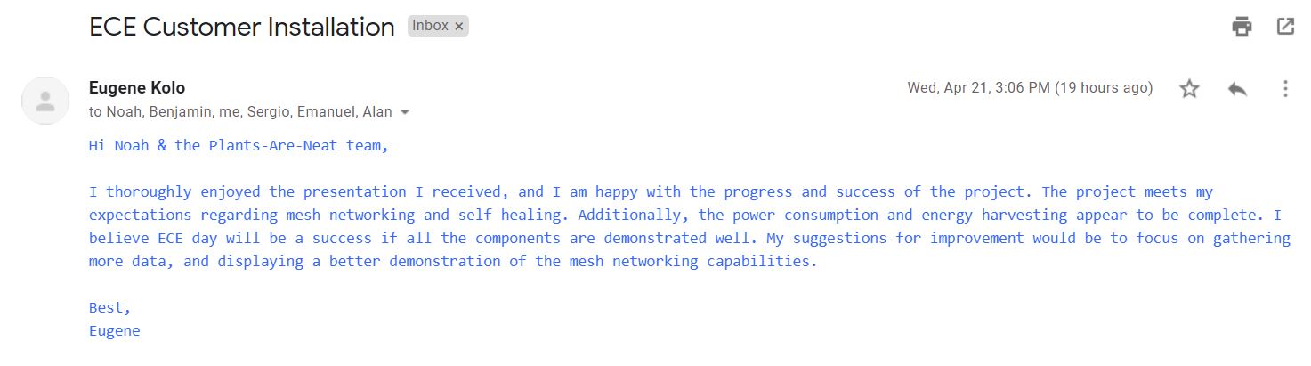
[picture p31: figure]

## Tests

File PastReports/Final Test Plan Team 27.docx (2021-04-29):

Memo


Senior Design

ENG EC 463

To: Professor Pisano, Professor Hirsch, Professor Osama

From: Ben Livney, Maxine Loebs, Sergio Pareja, Emanuel Perez, Noah Spahn

Team: 27 - Plants are Neat

Date: 4/5/21

Subject: Final Test Plan

1.0 Abstract

For our test, we have decided to show our progress in a few key areas of our project, namely node communication, power, and data display for the user. We will show that our nodes are able to communicate with one another and transmit data between LoRa modules to the gateway node, which can upload the data to be accumulated, parsed, and displayed by the website.

2.0 Required Software and Hardware Components

2.1 Hardware

- 2 Adafruit Feather M0 microcontrollers
- 1 custom PCB
- 1 enclosure with sensor probes and peripherals
- 1 USB - micro USB cable
  2.2 Software
- Arduino IDE
- MatLab IoT ThingSpeak
- RadioHead.h
- RH_RF95.h
- Node JS
- Batch Files

3.0 Communication + Collect Data + Visualization

3.1 Setup

- Upload all relevant code to each microcontroller, and make sure other website/node.js code is running.
- Insert sensor node 1 into the custom PCB.
- Plug in a 5V wall adapter to the PCB to simulate a solar panel.
- Attach the battery pack to the battery leads on the PCB.
- Initialize the Matlab ThingSpeak API via Node.js and open the website in a browser.
- Plug the gateway node into a laptop via a micro-USB cable

3.2 Network Procedure

- Mother node requests data from sensor nodes
- Sensor node receives request, collects current data from sensors, and send data to mother node
- Mother node receives data and sends it to computer
- Node JS server parses data and uploads to remote website
- Remote website displays the data in graphs

3.3 Console procedure

- Initialize the Node.js script that uploads data points to the ThingSpeak API.
- Open relevant gauges and graphs to verify data is being collected properly.

3.4 Network Criteria

- Poll is successfully sent to other nodes
- Outer node successfully sends uncorrupted sensor data back
- Mother node successfully sends to the mother computer

3.5 Console criteria

- Graphs should update with the data corresponding to the data points that are printed in the node.js script periodically.
- Data should reflect changing conditions (i.e. shining a light on the light sensor should increase the lux value).
- Website should display an error message when it hasn’t heard from a particular sensor node after 1 minute (adjustable).

3.6 Power criteria

- Test should be repeatable on “solar” power and on battery power and data streaming should not be interrupted.

4.0 Conclusion

After the conclusion of our tests, we determined that we are able to successfully transmit data between sensor nodes, implement a sleep wake system that bounces data between nodes, operate all electronics on battery and solar power, upload data and generate visualisation with collected sensor data. Our next task for our group is to finalize the optional features of our product and prepare it for customer installation and ECE day.

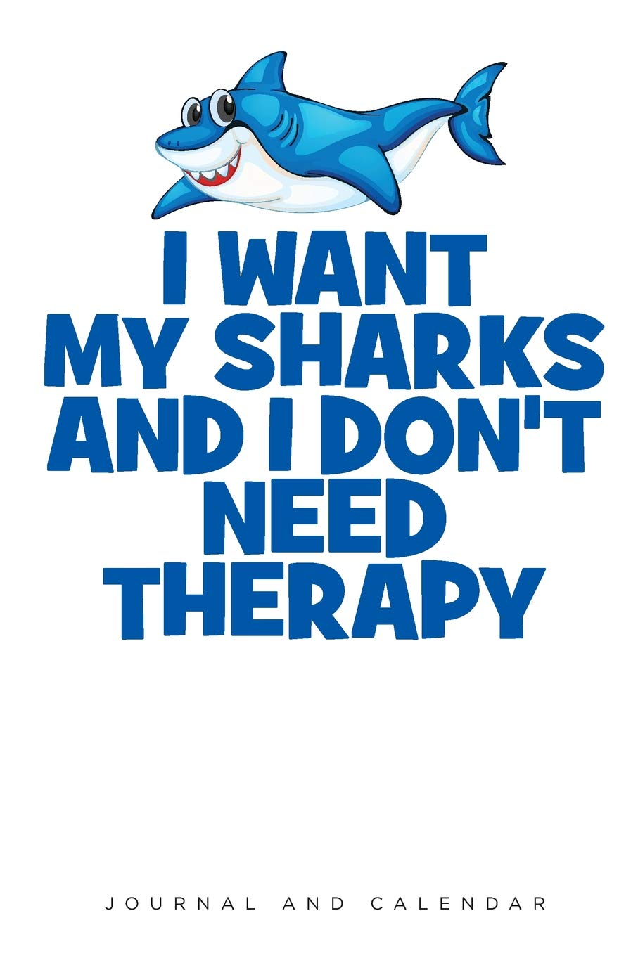
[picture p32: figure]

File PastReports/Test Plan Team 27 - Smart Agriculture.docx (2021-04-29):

Memo


Senior Design

ENG EC 463

To: Professor Pisano, Professor Hirsch, Professor Osama

From: Ben Livney, Maxine Loebs, Sergio Pareja, Emanuel Perez, Noah Spahn

Team: 27 - Plants are Neat

Date: 11/19/20

Subject: First Prototype Test Plan

1.0 Abstract

For our test, we have decided to show our progress in a few key areas of our project, namely node communication, power, and data display for the user. We will show that our nodes are able to communicate with one another and transmit data, that our solar panel is able to charge our battery, and both the solar panel and battery can deliver power to a load via a power path management IC, and that we are able to display data to the user for interpretation.

2.0 Required Software and Hardware Components

2.1 Hardware

- 2 Adafruit Feather M0 microcontrollers
- 1 BQ24074 module
- 1 3.5W 6V solar panel
- 1 3.7V Li-Ion battery pack, not fully charged
- 1 I²C sensor
  2.2 Software
- Arduino IDE
- MatLab IoT ThingSpeak
- RadioHead.h
- RH_RF95.h

3.0 Communication Between Nodes

3.1 Network Procedure

1. Mother Node sends poll request for a specific node to other nodes
2. If node is not the one requested, then the node sends the poll request to other nodes as well
3. Once the correct node is found, it sends data to the one asking for it
4. Data is passed around the nodes till it reaches the mother node

3.2 Network Setup

- One outer node and one mother node
- Network Protocol
- Transmission device (LoRa)

3.3 Network Criteria

- Poll is successfully sent to other nodes
- Poll successfully reaches the requested node
- Requested node successfully sends back it’s sensor data to the poll sender
- Mother node receives correct sensor data from the requested node
- Able to repeat the process to find all the nodes in the network
- If node is not requested but receives the poll, the node sends resends the poll to other nodes (closest one)

4.0 Solar Charging and Power Path Management

4.1 Solar Charging Procedure

- Connect the solar panel DC output to the DC input of the BQ24074 using the barrel connector.
- Connect the LiPo output of the BQ24074 to the positive terminal of the battery pack.
- Measure the battery voltage.
- Connect the GND output of the BQ24074 to the negative terminal of the battery pack.

4.2 Solar Charging Measurable Criteria

- When the solar panel is powering the BQ24074, a PGOOD LED should turn on.
- When charging is enabled, a charging LED indicator should turn on and a positive charging current should be measured.

4.3 Power Path Management Procedure

- Disconnect the battery pack from the BQ24074.
- Connect an LED and resistor in series to the load output of the BQ24074.
- Remove the solar panel and reconnect the battery.

4.4 Power Path Management Measurable Criteria

- When powered by the solar panel, the LED should turn on.
- When powered by the battery pack, the LED should also turn on.

5.0 Data Analysis and Visualization

5.1 MatLab Iot ThingSpeak

- Iot ThingSpeak tool used to connect the uplink node, database, analytical functionality and visualisation into a html output stream.

5.2 Data Representation

- Data is written and read as a csv file with the unique channel ID for each console uploading and doing analytics. This allows the systems to be scaled as more than one system can use the same procedures with different labeled data as long as more space is allocated on the server.

5.3 Software:

- MatLab 3 Scripts:
  - Read Data From Data Channel
  - Analyse and Generate Visualisation of Data
  - Write Data To Data Channel
- Html 1 Script:
  - Stream Visualisation to Html Webpage

5.4 Pre-Testing Procedure:

- Initial step of the Pre-Testing Procedure was to load previous data into each html page.
- Ensure any past Stream Visualisation analysis and visual is visible on the page.
- Ensure any past data points are noted before the test.

5.5 Testing Procedure:

- The html block is loaded and refreshed with an old data graph.
- Run MatLab channel write to add data to the channel.
- After a few seconds the html block will refresh with new sample data.
- Again Run MatLab channel write to add another data point to the channel.
- After a few seconds the html block will refresh with new sample data.

5.6 Measurable Criteria:

- Before Upload Data should stay constant.
- After Upload the graph should update to include new data points at the current timestamp.
- The visualisation should update without the whole page restarting.

5.7 Measurement Results:

- The graph refreshes itself without a page refresh.
- The graph updates data points after upload including only the additional data points added. including a timestamp with when the data was taken.

6.0 Using Sensor and Collecting Data

6.1 Setup

- Upload code onto board
- Connect the sensors

6.2 Collecting data

- Let the code run, get data readings on temperature and pressure
- Data will be displayed in serial monitor

6.3 Measurable criteria

- Readings are coming back accurately
- Demonstrate that readings change in response to change in temperature (can’t really vary pressure)

7.0 Conclusion

After the conclusion of our tests, we determined that we are able to successfully transmit data between sensor nodes, implement a sleep wake system that bounces data between nodes ,charge the battery we built with with the solar charger and solar panel, upload data and generate visualisation with collected sensor data. Our next task for our group is to continue working on the mesh network development so that it is better suited for scale as well as connecting all our components together that we were able to test out in the prototype. The wake protocole test will be connected to the data transfer test enabling us to wake and sleep nodes for data collection and transmission. The console node will then be connected to the uplink test using a wifi shield as our bridge between the board and the internet. This will enable the upload and updated visualisations using the most real time data available. Given we complete these tasks we would like to fully integrate the system into a single board allowing for a cleaner and more dependable solution.

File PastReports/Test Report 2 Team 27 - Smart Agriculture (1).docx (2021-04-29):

Memo


Senior Design

ENG EC 463

To: Professor Pisano, Professor Hirsch, Professor Osama

From: Ben Livney, Maxine Loebs, Sergio Pareja, Emanuel Perez, Noah Spahn

Team: 27 - Plants are Neat

Date: 02/25/2021

Subject: Second Prototype Test Report

1.0 Required Software and Hardware Components

1.1 Hardware

- 4 Adafruit Feather M0 microcontrollers
- 1 Custom made PCB
- 1 Solar panel (or benchtop power supply for indoor testing)

1.2 Software

- Arduino IDE
- MatLab IoT ThingSpeak
- RadioHead.h
- ESP8266WiFi.h
- RH_RF95.h
- Adafruit_Sleepydog
- RHMesh.h
- RHGenericDriver.h
- SPI.h
- WiFi.h
- HTTPClient.h

2.0 Mesh Communication Between Nodes

2.1 Network Procedure

The test uses three nodes. Two nodes are used as the outer nodes while the third node is the mother node. The mother node polls for three outer nodes, one of which is not connected to simulate a broken node. The use of mesh network functions are used to communicate between the nodes. The requested node listens to LoRa waves for their own specific ID to send their collected data to, otherwise it waits. In addition to this behaviour, the test also examines the success of conveying messages completely without any misplaced/missing characters.

2.2 Network Measurements

After the initialization of the nodes (flashing the code into the board), it only took one iteration to request and receive information from the desired outer node. Both message from and to the mother node was complete without any missing/mismatch characters. The behaviour was repeatable to other nodes (the rest of the network). Information was passed around efficiently by using the shortest path from the desired node to the mother node using the mesh network’s routing table. As a result, outer nodes do not fully communicate with each other unless it is necessary. Also, an error message was sent to the console when it was not able to communicate with a missing/broken node.

2.3 Network Conclusion

The test demonstrated the use of mesh network protocol to communicate successfully between outer nodes and mother nodes as well as between the outer nodes. The test is the foundation of further testing to find the longest possible range of communication between the nodes that exploit the mesh network’s routing table. The test also demonstrated the addition of more nodes will not cause any miscommunication or errors between the outer nodes.

3.0 Power Systems

3.1 Power Systems Procedure

To perform this test, the featherboard was inserted into the custom PCB, which was connected to

a benchtop power supply en lieu of a solar panel for indoor testing. The LiPo battery was

connected through an ammeter to the LiPo battery connector on the custom PCB. In order to

measure the relevant parameters for this test, the battery was connected to observe whether or

not the featherboard is turned on without the benchtop power supply. Then, the battery was

disconnected to observe featherboard activation, this time as a result of the power supply. Finally,

both the battery and benchtop power supply were activated to measure battery charging current

in relation to the power supply sink current.

3.2 Power Systems Measurable Criteria

When the battery only was connected, the battery’s sink current was 24mA, which was the featherboard’s required current draw. When the benchtop power supply only was connected, the power supply’s sink current was also 24mA, indicating that the featherboard was being properly powered from both sources. When both the battery and the power supply were connected, the battery charging current was 400mA, which is the programmed “fast charging” current on the PCB, and the power supply sink current was 424mA. This indicated that the power supply was simultaneously delivering power to the featherboard and sensors and charging the battery. This test showed that the featherboard will be able to be powered for long periods of time because of the constant charging of the backup battery and power delivery to the loads when sunlight is available, and proper battery power delivered to the loads when no sun is available.

4.0 Data Analysis and Visualization

4.1 MatLab Iot ThingSpeak

Iot ThingSpeak tool used to connect the uplink node, database, analytical functionality and visualisation into a html output stream.

4.2 Data Representation

Data is written and read as strings with the unique channel ID for each console uploading and doing analytics on independent data. This allows the systems to be scalable as more than one system can use the same procedures with custom labeled data as long as more space is allocated on the server.

4.3 Software:

- Arduino 2 Scripts:
  - Multi-Channel Update
  - Server Credentials
- MatLab 1 Script:
  - Analyse and Generate Visualisation of Data
- Html 1 Script:
  - Stream Visualisation to Html Webpage

4.4 Pre-Testing Procedure:

Initial Testing was done with an empty channel and no data in the ID set. Micro-controllers working as the Gateway were connected to power through non-serial usb connection. There are 2 readings that can be taken from the Gateway itself in terms of its onboard hall sensor and CPU temperature sensor. These sensors were used as data points to demonstrate the data path during the test. Ensuring the data test works within a 2.4GHz wifi network was also important for determining the rationale behind server side rejected packets.

4.5 Testing Procedure:

The testing procedure involved initialising the gateway and connecting it to non-serial usb power. The gateway was then let alone for 5 minutes to ensure no user action was required for subsequent data-point upload. The gateway was then reset manually to ensure power interruptions wouldn't interrupt the stream of data from the gateway to the server.

4.6 Measurable Criteria:

Measurable criteria in this test included expectations of datapoints uploaded into channel ID 1310790 field 1 and increment from 0-100 in steps of 9. After reaching threshold the data needs to reflect both on the thingspeak server as well as the google gauges javascript visualisation.

4.7 Measurement Results:

Testing resulted in an expected upload to channel ID 1310790 field 1 in increments on 9. After the reset the patterns started again without intervention. The Google Gauge Visualisation as well as the thingspeak App updated in line with the data within each channel field noting both the data point as well as time of successful upload. Prior to testing -301 error was found often demonstrating a failure of a packet to upload . This was corrected by disconnecting and reconnecting the gateway to the network after each upload to avoid thingspeak blocking subsequent uploads.

5.0 Using Sensor and Collecting Data

5.1 Setup

To set up the sensor test, the relevant code that streams sensor data to the serial monitor was

uploaded to a featherboard. The featherboard was then inserted into the custom PCB that has all

of the sensors included.

5.2 Collecting data

After letting the code run for some time, it was evident that the data that was being collected was the sensor data, as the temperature sensors read 80 degrees fahrenheit, the humidity sensor read 5%, and the lux and soil moisture sensors reacted to changes in ambient light and moisture on the probe respectively.

5.3 Measurable criteria

To determine if the sensor data that was collected was accurate, each temperature sensor was warmed via holding it with a finger, and the temperature, as well as humidity, were observed to increase. Similar results were gathered for the lux sensor with respect to increases in ambient light and the soil moisture sensor with respect to the amount of moisture increasing on the sensor’s probe.

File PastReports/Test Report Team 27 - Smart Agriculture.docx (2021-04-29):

Memo


Senior Design

ENG EC 463

To: Professor Pisano, Professor Hirsch, Professor Osama

From: Ben Livney, Maxine Loebs, Sergio Pareja, Emanuel Perez, Noah Spahn

Team: 27 - Plants are Neat

Date: 11/22/20

Subject: First Prototype Test Report

1.0 Required Software and Hardware Components

1.1 Hardware

- 2 Adafruit Feather M0 microcontrollers
- 1 BQ24074 module
- 1 3.5W 6V solar panel
- 1 3.7V Li-Ion battery pack, not fully charged
- 1 I²C sensor

1.2 Software

- Arduino IDE
- MatLab IoT ThingSpeak
- RadioHead.h
- RH_RF95.h

2.0 Communication Between Nodes

2.1 Network Procedure

For purposes of the test, only two nodes were used. There will be one outer node and one mother node. The mother node polls for certain node IDs to respond, and if the ID coincides with the node, then it sends a reply. The reply for this test is a simple acknowledgment . If the outer node does not coincide, then the outer node relays the message to all around nodes, so that it can find the correct node. The nodes communicate using their built-in LoRa radios.

2.2 Network Measurements

Sending the poll request to listening nodes only took two iterations (each iteration is about half a second). In other words, the mother node only sends two poll requests before receiving a reply. The information retrieved has all the information unaltered from the outer node. The outer node only sends the information if the poll requested the specific node ID, otherwise the outer node sends a reply of acknowledgement. The acknowledgement is sent successfully in one iteration. When the outer node receives a poll request for another node, it sends the poll request to other nearby nodes (in addition to sending the acknowledgment). At this point, the mother node waits for the information from the outer node, and the outer node waits for a different node to listen to it’s poll request.

2.3 Network Conclusion

The test proved a reliable method of conveying information between nodes and working a network. With the addition of improved antennas, the nodes will be able to communicate to each other in a longer range (currently about three hundred meters). The addition of other nodes into the network is possible since the protocol only depends on the node ID which is unique to each node. As a result, a network of multiple nodes is possible with the current software. Next steps would involve the addition of other test sections (solar charging, gathering of sensor data, visualization) to the current hardware and software.

3.0 Solar Charging and Power Path Management

3.1 Solar Charging Equipment and Setup

For this test, a BQ24074 module, a 3.7V Li-Ion or LiPo battery, a multimeter, and a power

supply are required. The BQ24074 was connected to the power supply via its Vin and GND

terminals, and its battery output was connected to the positive terminal of the battery. The negative terminal of the battery was also connected to ground through the multimeter current setting. A simple resistor and LED were used as a demonstration load.

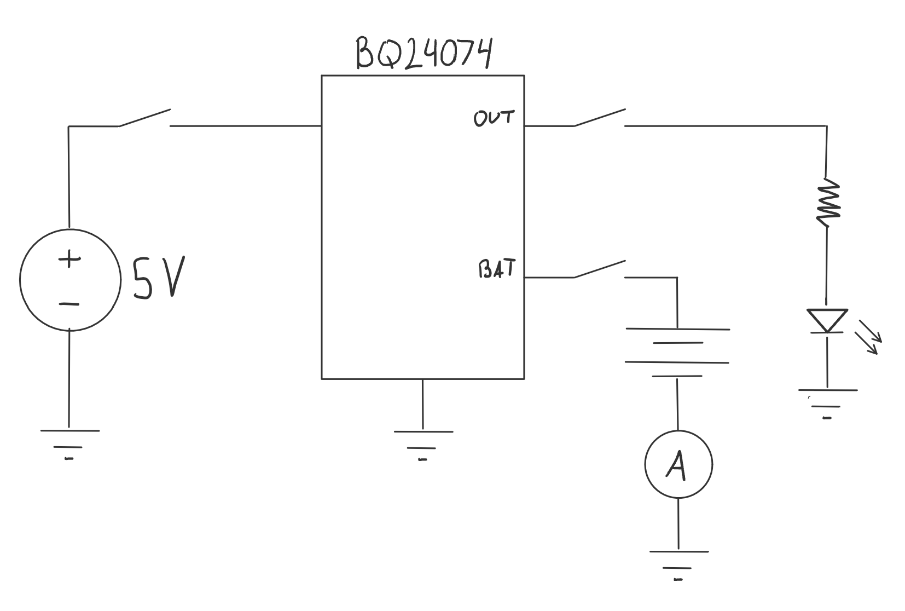
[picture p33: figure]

3.2 Solar Charging Measurements Taken

Before taking current measurements, the battery voltage was measured with the

multimeter to be 3.19V, indicating that the battery is not fully charged. While the battery

was connected to the BQ24074, the power supply was turned on to 5V. While on the 1A setting, the ammeter in series with the battery read 899mA, signaling that the battery is being charged with nearly 1A of current. Next, the ammeter and battery were disconnected and the demonstration load was connected to the BQ24074 load output while powered from the power supply. The LED was lit, indicating that the BQ24074 is able to power a load from an external source. Then, the power supply was disconnected and the battery was reconnected, and the LED remained lit, indicating that the BQ24074 is capable of powering the load from the battery with no external source.

3.3 Solar Charging Conclusions from Data Taken

Based on these tests, the BQ24074 is a great choice for solar charging and power path

management for the project. It is capable of charging a Li-Ion battery with a high

programmable charging current, and of managing the powering of a load from an external source and a battery. Not shown in these tests due to the testing occurring indoors is the solar charging, which was tested beforehand independently with a 6V 3.5W solar panel. Together, they were able to charge the battery with up to 160mA on a partly cloudy day, and with up to 50mA with obstruction of the panel. From this, we can conclude that even in poorer light conditions than expected, the battery can be charged from a solar panel with the BQ24074 to some degree, and can draw enough current from the solar panel to power the microcontroller and all the sensors.

4.0 Data Analysis and Visualization

4.1 Equipment and Setup

Iot ThingSpeak tool is used to connect the uplink console node, database, analytical functionality and visualisation into a html output stream. Data is written and read as an array with the unique channel ID for each unique console uploading data as well as an identical script set running different analytics. This allows the systems to be scaled as more than one system can use the same analytical analysis tools as long as more space is allocated on the server for storing additional data.

4.2 Testing Procedure

To test the web app visualization a html page was loaded receiving a visualization from the private thingspeak channel 18991. This channel is receiving data from a MatLab script running on my local machine. For the test we will note previous data points, upload new data to the private channel. Finally waiting briefly to observe the change in the webApp visualisation. Concluding this process we should have a general understanding of whether the web app is correctly receiving and visualising data.

4.3 Visualisation Measurements

The measurements from the test were taken in comparison to the measurements uploaded to the ThinkSpeak Server. A successful test was noted by identical data points being uploaded and subsequently represented in the visualisation. What we saw in this case was a successful test of a data point 43.3 posted at 4:48:37 and a subsequent data point 100.3 posted at 4:48:56 was visualised with identical values and timestamps in the visualisation.

4.4 Conclusion

After concluding the test we can be sure that the method of uploading and representing data visually is working. Data points can be uploaded with a minimum time in between of 19 seconds. Given our constraints, this method of data transfer and visualisation will work for a consol housed in a wifi accessible area. Given that the minimum time between data points is 19 second we cannot stream more data than this hypothetical maximum but given our power restraints restrict us from sending data more than once every few minutes this is of no consequence. If the console lags behind in uploading for whatever reason and has a que to get through each set of sensor data should have a 20 second stall between uploads to the data stream to avoid errors. Next steps for the development future development would be to integrate the test working on receiving data into the upload mechanic to automatically send any data received by the console to its appropriate data channel.

5.0 Using Sensor and Collecting Data

5.1 Equipment and Setup

For this test, we used two sensors (temperature and barometric pressure) to prove we can collect live and accurate data from the nodes. As a result, we uploaded code to read from the sensors and print the results to the serial monitor for verification.

5.2 Measurements Taken

During the test, the code for reading the sensors was successfully uploaded to the board. The code returned data readings every second (temperature and barometric pressure). The pressure readings returned were in line with normal readings at an altitude close to sea level. The temperature readings were initially coming back at about 65 degrees Fahrenheit. To show the sensor accurately picking up changes in temperature, I moved the sensor in front of my heater. The temperature began to consistently rise, changing by about 1 degree per data reading.

5.2 Conclusion

We were able to show that our sensor is responsive to changes in temperature. The data was updated accurately every second. Next steps include integrating all of our sensors onto a PCB.

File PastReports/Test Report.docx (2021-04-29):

Memo


Senior Design

ENG EC 463

To: Professor Pisano, Professor Hirsch, Professor Osama

From: Ben Livney, Maxine Loebs, Sergio Pareja, Emanuel Perez, Noah Spahn

Team: 27 - Plants are Neat

Date: 4/9/21

Subject: Final Test Report

1.0 Required Software and Hardware Components

1.1 Hardware2 Adafruit Feather M0 microcontrollers

- 1 custom PCB
- 1 enclosure with sensor probes and peripherals
- 1 USB - micro USB cable

1.2 Software

- Arduino IDE
  - ServerClient
  - MotherNode
- RadioHead.h
- RH_RF95.h
- MatLab IoT ThingSpeak
- Node JS
  - SerialTest.js
- Batch Files
  - PANinstall
  - runMESH

2.0 Completed Tests

2.1 Network Tests

The test had three microcontrollers communicating with each other (depending on their individual role). The mother node sent a request to each node for sensor data. Each outer node received the mother node request, collected data from sensors, and sent the data back to the mother node. The mother sent the collected data to the computer via serial port.

2.2 Network Conclusions

The test demonstrated communication between the nodes successfully. Collected data from the outer nodes were accurate, and it was sent successfully to the mother node without any package lost. The mother node uploaded the data via serial to the computer. The computer received the data without any corruption (the same string as the string sent by the outer node).

2.3 Console Tests

The test here is composed of three different files: 1 nodejs file titled SerialTest and 2 batch files labeled runMESH and PANinstall. The SerialTest file is for reading from the COM ports to interact with the mothernode to send information to the IOT thingspeak channel. The batch files are for the users convenience, PANinstall installs all NodeJS dependencies they need and the runMESH runs the SerialTest.js code.

2.5 Console Conclusions

The test demonstrated proper acquisition of data from the mother node and correct updating of online elements. The serial reading works properly and the information is stored within the computer almost instantaneously. The batch files also properly run and install everything, same as if using the command line to install all NodeJS dependencies but faster and easier.

2.6 Power

Unfortunately, logistics and planning did not allow for us to gather all of the necessary materials to perform a battery-operated networking test. We could, however, show that the power path management electronics work well while using only solar power. We were able to show in the second prototyping test successful power path management with solar and battery power, without the networking component. Powering the featherboards allows any sketch to run on the processor, and we have run networking sketches on the featherboards while being powered from battery power via the power electronics, but have not updated data to the console using this setup. We anticipate that it will easily be possible to add the battery power to the networking, as we have demonstrated all the necessary components before.

2.7 Website/Notifications Test

The test had a single channel with five fields that were reading from the things peak API. This channel was cleared of all data so new data could be read into the track when the test was initialized. Data was demonstrated over time graphically with point-slope graphs and real-time gauges displaying the most recent data point. Notifications are handled with a Matlab script checking fields whenever variables are uploaded. This is similar to the notification function as it triggers a Matlab script when no data has been read into the channel after 30min of no activity. These visualizations received data from the medium and would update when information was successfully uploaded to the track.

2.8 Website/Notifications Conclusion

During the test, data was uploaded to the channel and demonstrated live updating on the track. When we pushed the fields outside of the thresholds, we got related communication in an email notifying the datapoint breached and the node it has been breached on. Similarly, when we remove a node for some time, we see a broken node notification trigger after the channel hasn't received data for over-the-set testing.

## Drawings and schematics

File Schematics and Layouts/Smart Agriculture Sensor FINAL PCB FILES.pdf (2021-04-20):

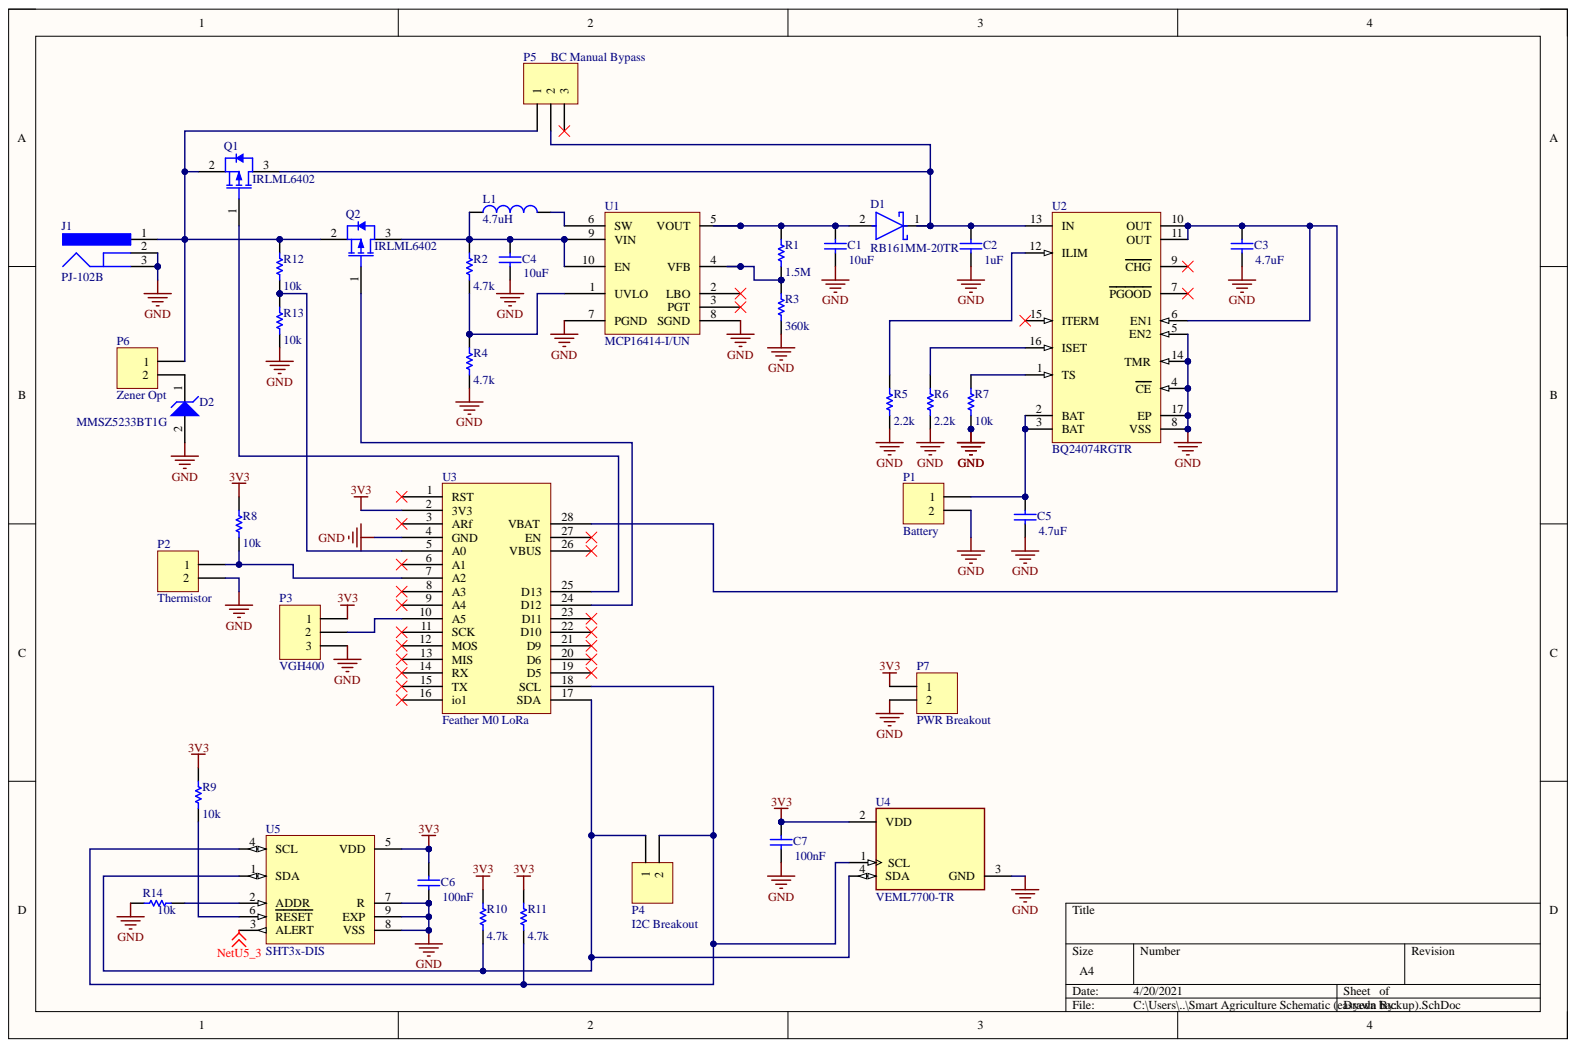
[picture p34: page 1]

A2 7
A3 8

SDA 1

SDA 4

RESET 6

Date: 4/20/2021 | Sheet of
File: C:\Users\..\Smart Agriculture Schematic (easyeda Drawnbackup).SchDoc By:

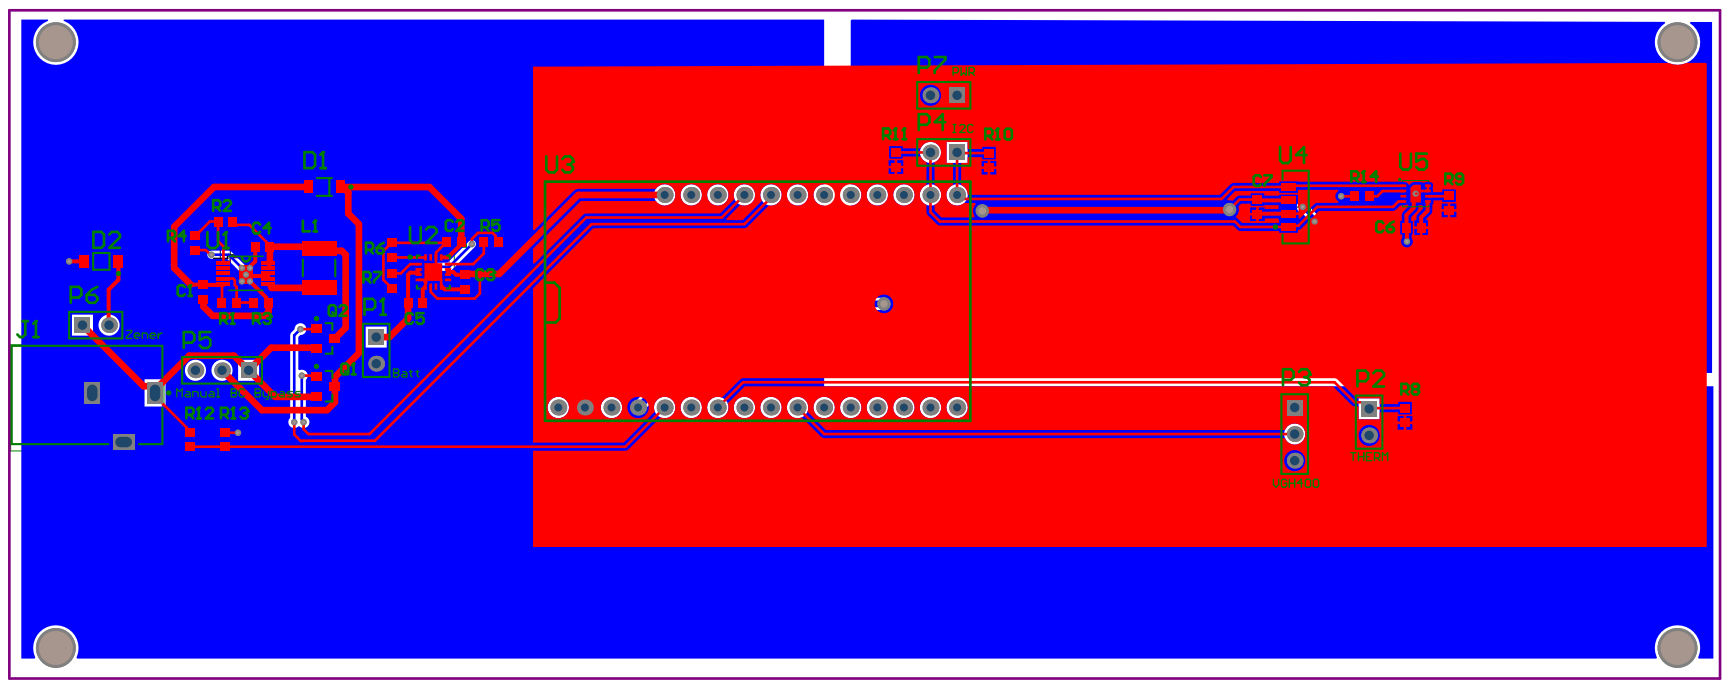
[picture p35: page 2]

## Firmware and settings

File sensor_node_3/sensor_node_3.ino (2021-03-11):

// modified from rf22_mesh_server 
#define RH_MESH_MAX_MESSAGE_LEN 50
#define RF95_FREQ 915.0

#include <RHMesh.h>
#include <RH_RF95.h>
#include <RHGenericDriver.h>
#include <RHRouter.h>
#include <SPI.h>
#define THERM A2
#define VH400 A5
#include "Adafruit_VEML7700.h"
#include "Adafruit_SHT31.h"
#include <Adafruit_SleepyDog.h>

#define CLIENT_ADDRESS 1
#define SERVER1_ADDRESS 2
#define SERVER2_ADDRESS 3
#define SERVER3_ADDRESS 4

#define RFM95_CS 8
#define RFM95_RST 4
#define RFM95_INT 3

//radio driver
RH_RF95 driver(RFM95_CS, RFM95_INT);

// set up manager
RHMesh manager(driver, SERVER3_ADDRESS);

// Initialization of sensors
Adafruit_VEML7700 veml = Adafruit_VEML7700();
Adafruit_SHT31 sht = Adafruit_SHT31();

void setup() 
{
  pinMode(RFM95_RST, OUTPUT);
  digitalWrite(RFM95_RST, HIGH);
  Serial.begin(9600);
  while(!Serial)
  pinMode(THERM, INPUT);
  pinMode(VH400, INPUT);
  // Setup VEML7700
  veml.begin();
  veml.setGain(VEML7700_GAIN_1_8); // largest light range
  veml.setIntegrationTime(VEML7700_IT_100MS);
  // Setup SHT31-D
  sht.begin(0x44);
  if (!manager.init())
    Serial.println("init failed");
  while (!driver.init()) {
    Serial.println("LoRa radio init failed");
    Serial.println("Uncomment '#define SERIAL_DEBUG' in RH_RF95.cpp for detailed debug info");
    while (1);
  }
  Serial.println("LoRa radio init OK!");
     
 // Defaults after init are 434.0MHz, modulation GFSK_Rb250Fd250, +13dbM
  if (!driver.setFrequency(RF95_FREQ)) {
   Serial.println("setFrequency failed");
   while (1);
   }
   Serial.print("Set Freq to: "); Serial.println(RF95_FREQ);
   driver.setTxPower(23, false);
}


// Collect Data function
String collectData() {
  // Get soil temperature with thermistor
  float resistance = analogRead(THERM); // get 0-1023 value from thermistor
  resistance = (1023 / resistance) - 1;
  resistance = 10000.0 / resistance; // get thermistor actual resistance
  float B = 3935; // depends on the NTC model
  float soiltemp = log(resistance / 10000) / B;
  soiltemp += 1.0 / (25 + 273.15);
  soiltemp = 1.0 / soiltemp;
  soiltemp -= 273.15; // apply thermistor characteristic B parameter equation
  soiltemp = soiltemp * (9.0 / 5.0) + 32; // units of degrees F
  soiltemp = round(soiltemp * 10) / 10; // one decimal place
  
  // Get soil moisture with VH400
  float moisture = analogRead(VH400); // get 0-1023 value from VH400
  float maxMoistureVoltage = (3 * 1023) / 3.3; // VH400 output voltage is 0V - 3V
  moisture = map(moisture, 0, maxMoistureVoltage, 0, 100); // units of %
  moisture = round(moisture * 10) / 10; //one decimal place
  
  // Get lux from VEML7700
  float lux = veml.readLux(); // units of Lux
  lux = round(lux * 10) / 10; // one decimal place

  // Get temp and humidity from SHT31-D
  float temp = sht.readTemperature() * (9.0 / 5.0) + 32; // units of degrees F
  temp = round(temp * 10) / 10; // one decimal place
  float humidity = sht.readHumidity(); // units of %
  humidity = round(humidity * 10) / 10; // one decimal place
  
  // Return data
  String results = String(temp) + "," + String(humidity) + "," + String(lux) + "," + String(moisture) + "," + String(soiltemp);
  return results;
}
void Sleep(int Time)
  { // Determine the amount of loops needed to reach the goal of sleeping for "Time"
    int rem = 0, stime = 0;
    rem = Time % 10;
    stime = (Time-rem)/10;
    if(stime >= 1) // In case sleeping is only needed less than 10 s
    {
      for(int i = 0; i < stime; i++)
        Watchdog.sleep(10000);
    }
    
    if(rem > 0) // In case of remainder being 0 (multiple of 10)
      Watchdog.sleep(rem*1000);
  }


uint8_t data[50];
// Dont put this on the stack:
uint8_t buf[RH_MESH_MAX_MESSAGE_LEN];
int sleepFlag = 0;
void loop()
{
  int i;
  uint8_t len = sizeof(buf);
  uint8_t from;
  String datapoints = collectData();
  for(i = 0; i < sizeof(data); i++)
    data[i] = 0;
  for(i = 0; i < datapoints.length(); i++)
    data[i] = datapoints[i];
  if (manager.recvfromAck(buf, &len, &from))
  {
    Serial.print("got request from : 0x");
    Serial.print(from, HEX);
    Serial.println(": ");
    Serial.println((char*)buf);

    // Send a reply back to the originator client
    if (manager.sendtoWait(data, sizeof(data), from) == RH_ROUTER_ERROR_NONE)
      sleepFlag = 1; // When it sends the information successfully, go to sleep
    else
      Serial.println("sendtoWait failed");
  }
 for(i = 0; i < sizeof(buf); i++) // Reset
    buf[i] = 0;
    
 if(sleepFlag){
  Sleep(300); // Sleeps for 30 secs
  sleepFlag = 0;
 }
}

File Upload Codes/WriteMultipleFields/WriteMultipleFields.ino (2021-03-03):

/*
  WriteMultipleFields
  
  Description: Writes values to fields 1,2,3,4 and status in a single ThingSpeak update every 20 seconds.
  
  Hardware: ESP32 based boards
  
  !!! IMPORTANT - Modify the secrets.h file for this project with your network connection and ThingSpeak channel details. !!!
  
  Note:
  - Requires installation of EPS32 core. See https://github.com/espressif/arduino-esp32/blob/master/docs/arduino-ide/boards_manager.md for details. 
  - Select the target hardware from the Tools->Board menu
  - This example is written for a network using WPA encryption. For WEP or WPA, change the WiFi.begin() call accordingly.
  
  ThingSpeak ( https://www.thingspeak.com ) is an analytic IoT platform service that allows you to aggregate, visualize, and 
  analyze live data streams in the cloud. Visit https://www.thingspeak.com to sign up for a free account and create a channel.  
  
  Documentation for the ThingSpeak Communication Library for Arduino is in the README.md folder where the library was installed.
  See https://www.mathworks.com/help/thingspeak/index.html for the full ThingSpeak documentation.
  
  For licensing information, see the accompanying license file.
  
  Copyright 2020, The MathWorks, Inc.
*/

#include <WiFi.h>
#include "secrets.h"
#include "ThingSpeak.h" // always include thingspeak header file after other header files and custom macros

char ssid[] = SECRET_SSID;   // your network SSID (name) 
char pass[] = SECRET_PASS;   // your network password
int keyIndex = 0;            // your network key Index number (needed only for WEP)
WiFiClient  client;

unsigned long myChannelNumber = SECRET_CH_ID;
const char * myWriteAPIKey = SECRET_WRITE_APIKEY;

// Initialize our values
int number1 = 0;
int number2 = random(0,100);
int number3 = random(0,100);
int number4 = random(0,100);
String myStatus = "";

void setup() {
  Serial.begin(115200);  //Initialize serial
  while (!Serial) {
    ; // wait for serial port to connect. Needed for Leonardo native USB port only
  }
  
  WiFi.mode(WIFI_STA);   
  ThingSpeak.begin(client);  // Initialize ThingSpeak
}

void loop() {

  // Connect or reconnect to WiFi
  if(WiFi.status() != WL_CONNECTED){
    Serial.print("Attempting to connect to SSID: ");
    Serial.println(SECRET_SSID);
    while(WiFi.status() != WL_CONNECTED){
      WiFi.begin(ssid, pass);  // Connect to WPA/WPA2 network. Change this line if using open or WEP network
      Serial.print(".");
      delay(5000);     
    } 
    Serial.println("\nConnected.");
  }

  // set the fields with the values
  ThingSpeak.setField(1, number1);
  ThingSpeak.setField(2, number2);
  ThingSpeak.setField(3, number3);
  ThingSpeak.setField(4, number4);

  // figure out the status message
  if(number1 > number2){
    myStatus = String("field1 is greater than field2"); 
  }
  else if(number1 < number2){
    myStatus = String("field1 is less than field2");
  }
  else{
    myStatus = String("field1 equals field2");
  }
  
  // set the status
  ThingSpeak.setStatus(myStatus);
  
  // write to the ThingSpeak channel
  int x = ThingSpeak.writeFields(myChannelNumber, myWriteAPIKey);
  if(x == 200){
    Serial.println("Channel update successful.");
  }
  else{
    Serial.println("Problem updating channel. HTTP error code " + String(x));
  }
  
  // change the values
  number1++;
  if(number1 > 99){
    number1 = 0;
  }
  number2 = random(0,100);
  number3 = random(0,100);
  number4 = random(0,100);
  
  delay(20000); // Wait 20 seconds to update the channel again
}

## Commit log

2020-10-12 Add Arduino sketch with collectData() function and code skeleton
2020-10-12 Add Arduino sketch with collectData() function
2020-10-29 Add temperature/pressure sensor test code
2020-10-29 remove temp pressure i am bad at github
2020-10-29 Add temperature/pressure sensor test code updated ver
2020-11-05 Added some sleeping code
    Currently, only adding code that will effect the sending part.
2020-11-05 Combine certain behaviors for energy conservation
    Simple implementation of each board sending information then receiving information to then sleep. The receiving end can also add another sending information thus moving around information. However, it stops sending/receiving once a board receives/sends. This could lead towards the prototype since it can automatically setup communication within 3-4 boards. Further consideration once adding sleep since it adds bugs in the flagging section.
    [SendSleep.ino]
2020-11-09 Add first prototype test code for node and gateway
2020-11-10 Compilation of previous code with added work flow
    Re-arrange some functions while adding new functions like sleep. Currently, it worked to send a string from one board to another board thus three boards communicating automatically.
2020-11-16 Add schematics and preliminary PCB BOM
    [Smart Agriculture Schematic.SchDoc, Smart Agriculture Sensor.PrjPcb]
2020-11-19 Fixed a bug
    Bug involved comparing strings instead of just comparing integers.
    [PollNetwork.ino.ino]
2020-11-19 Update for Demo
    Links switch between pages, matlab program uploads dummy data to new channel and live analytics visualisation is possible as well as reading long term from data channels.
2020-11-24 Update schematics
    [Smart Agriculture Board.PcbDoc, Smart Agriculture Schematic (easyeda backup).SchDoc, Smart Agriculture Schematic.SchDoc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]
2020-11-24 Routed power path management system
    [Smart Agriculture Board.PcbDoc]
2020-11-27 Finish routing
    [Smart Agriculture Board.PcbDoc, Smart Agriculture Schematic (easyeda backup).SchDoc]
2020-12-08 Sourced component footprints and added mechanical cutouts
    [Smart Agriculture Board.PcbDoc, Smart Agriculture Schematic (easyeda backup).SchDoc, Smart Agriculture Sensor.PrjPcb]
2020-12-08 Source component footprints and add mechanical cutouts
2021-01-26 Replace BME280 polling with SHT31-D polling
    [node.ino]
2021-01-29 Update sensor_node_1.ino
    Same as the previous commit
2021-01-30 driver update
2021-01-30 small fix in serial output
    [client_node.ino]
2021-02-06 Add soil moisture sensor code
2021-02-15 Send real sensor data
2021-03-03 Website Update
    Uploaded Layout, Nav and graph Page. Next need to link to real sensor data and add some info to gallary page.
2021-03-06 Legal US ISM Band quick fix :^)
    [client_node.ino, sensor_node_1.ino, sensor_node_2.ino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]
2021-03-14 Remove the error message
    [client_node.ino]
2021-04-20 Upload most up to date schematics and layouts
    [Smart Agriculture Board.PcbDoc, Smart Agriculture Schematic (easyeda backup).SchDoc, Smart Agriculture Schematic.SchDoc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]
